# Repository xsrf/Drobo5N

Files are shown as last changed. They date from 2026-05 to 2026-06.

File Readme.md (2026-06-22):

# Drobo 5N Reverse-Engineering
My Drobo 5N (Unit 1) died on me in May 2026. Here are some random notes and resources I gathered, trying to find out what happened.
It looks like one of the three 2 channel SATA Controllers died (more on that later).
I also bought another Drobo 5N (Unit 2) from eBay, to check some of my assumptions.

My assumption was later confirmed. One SATA controller had a bad 1V voltage rail due to a burnt out transistor. Simply replacing that transistor (Q2) fixed the issue.

## Directory Contents

| Directory | Description |
|---|---|
| [3D](3D/) | OpenSCAD and 3D-print files (PCB carriers to help working on the PCB on the desk) |
| [Disassembly](Disassembly/) | Disassembly instructions including images |
| [Datasheets](Datasheets/) | Component datasheets and reference material |
| [gfx](gfx/) | Images used in this repo (figures and photos) |
| [MSP430](MSP430/) | Tools for MSP430 and flash dumps of both units |
| [Unit1](Unit1/) | Unit 1: crashlogs, bootlogs, traces (PulseView), and USB-DOM files/image |
| [Unit2](Unit2/) | Unit 2: crashlogs, bootlogs, traces (PulseView), USB-DOM files |
| [USB-DOM](USB-DOM/) | Disk-on-module images and vxWorks files |

## Crashlog Recovery

### USB DOM (Disk on Module)
The Drobo 5N comes with a 1GB FAT16 formatted internal USB drive. It uses a module which is connected using a 2mm pitch internal USB connector (like the ones on a regular PC motherboard, but smaller). You can make yourself an adapter with 2mm pitch Header-Pins.

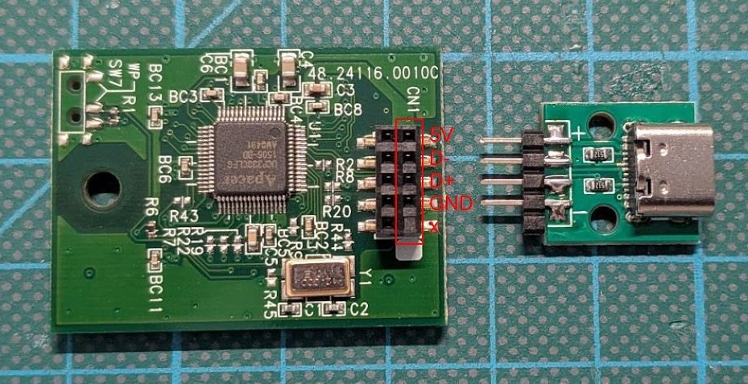
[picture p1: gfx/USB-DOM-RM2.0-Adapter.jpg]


The module holds Crashlogs (basically the whole output of the Drobis internal VxWorks system) which hold valuable information for debugging.

### Crashlogs (Unit 1)
The [crashlogs](Unit1/USB-DOM/UBSW/Crashlogs) I recovered from my unit have a time offset of about ~9h to MESZ. 2026-05-03 03:19 MESZ ~= 2026-05-02 18:19 in log.  
- [crashlog-20260504-1210](Unit1/USB-DOM/UBSW/Crashlogs/crashlog-20260504-1210) shows drobo crashing
- [crashlog-20260504-1211](Unit1/USB-DOM/UBSW/Crashlogs/crashlog-20260504-1211) shows the reason on next bootup: *diskInterfaceInitialise: Adapter 1 Init Failed*

### Timeline (Unit 1)
Together with my local monitoring and my own observations, the crashlogs allow me to reconstruct what happened:
- 2026-05-01 19:34 MESZ Disk 3 dropped out?!?! (Most recent timestamp via UFS Explorer recovery of Disk 3)
- 2026-05-03 03:19 MESZ (+-5min) Drobos httpd went offline (Timestamp via Monitoring)
- 2026-05-04 20:49 MESZ Me noticing Drobo being off with top slot green, 2nd slot red; No sign in Dashboard
- 2026-05-04 20:.. Tried to power off via Switch. Got untill all lights went dark but drive and fan didn't power down even after ~15 minutes; Removed Power-Plug
- 2026-05-04 20:.. Plugged back in, booted, all lights yellow, after few min top red, rest off; Dashboard sees Drobo and says no drives; Drives did not spin up!
- Powered on again without drives then inserted one totally different drive - did not spin up!

## Other components

### Battery
The Battery is a 3.6V 2150mAh Li-Ion 18650 (Panasonic CGR 18650 CH). Model "Bumblebee b".
I measured:
- 4.12V between Red and Black under slight load (Multimeter Low-Z)
- 10k between Green and Black
Looks perfectly fine

### Power-Switch
| Wire | Function |
| --- | --- |
| Blue | Switched to white -> pulls up MSP430 P1.1 |
| White | 3V supply; LED anode |
| Red | LED kathode -> pulled down by MSP430 P4.6 via Q87 |

### Power-Switch LED
During debugging I've observed many flashing patterns
| Signal | Meaning |
| --- | --- |
| on continously | System on; normal operation |
| off continously | System off/stand-by |
| 3x 790ms, 4x 160ms, repeating | Performing Shutdown |
| on 256ms, off 256ms, repeating | System on; PMU (v78) in failsafe mode! |
| extremely faint short flash every ~500ms | PMU (v78) reset-loop |
| one 330ms flash (and short fan twitch) | PMU (v78) enters Failsafe Stand-By after power connect / reset |
| one 300ms, 3x 80ms, 3x 160ms, 3x 80ms, 2x 160ms (and short fan spinup) | PMU (v7a) enters regular Stand-By after power connect / reset |

### PMU - MSP430F2252
The PMU (Power Management Unit) of the Drobo is a MSP430F2252. It's responsible for handling the Power-Switch, Power-Switch LED, Power-On/Stand-By behaviour and brings up additional power-rails for the SoC, other controllers and Fan.

When the PMU is held in reset, the FAN and Power Switch LED are turned on!

#### J11 - MSP430F2252 programming header

J11 (not populated 0.1" header) exposes the programming / debugging pins of the MSP430.

| Pin | Function |
| --- | --- |
| 1 | 3V (marked) |
| 2 | TEST |
| 3 | RST |
| 4 | GND |

Jumper J13 must be removed in order to debug/reset/flash the MSP during operation.
While flashing, FAN might tun on.
Didn't try supplying 3V through J11.

#### Flash/Memory Layout
| Range | Name | Info |
| --- | --- | --- |
| 0x0C00 - 0x0FFF | Boot | 1kb; Identical on Unit1/Unit2; probably stock TI |
| 0x1000 - 0x10FF | Info | 256b; INFOD to INFOA |
| 0xC000 - 0xFFFF | Main/Code | 16kb |

Remove J13 to read/write to MSP430 while drobo is powered (plugged in is enough).

#### Info Segments
| Range | Name | Info |
| --- | --- | --- |
| 0x1000 - 0x103F | Info D | PMU version; static values; programmed with PMU update |
| 0x1040 - 0x107F | Info C | PMU runtime information; updated on every reset and power-up |
| 0x1080 - 0x10BF | Info B | static informatiion?! |
| 0x10C0 - 0x10FF | Info A | FF + Chip calibration values at end; write protected |

Only Info D is written when a PMU update is performed by the VxWorks system. 

#### Info C
0x105B (unit8) (probably 0x105A uint16) looks like it contains a counter that increments with every boot-up of the system

0x1065 (unit8) (probably 0x1064 uint16) contains a counter that's incremented whenever the PMU starts

#### UART to SoC
The PMU has a 38400 baud UART connection to the main SoC via Pins UCA0RXD/UCA0TXD. It communicates via 0x00 terminated ASCII strings.
Communication can be observed in [powerup_01_safemode_pmu_update.sr](Unit1/Trial-20260621-01/powerup_01_safemode_pmu_update.sr).
Whenever the PMU parses a command from the SoC, the power switch LED goes off (which is to fast to notice in real life).

### PMU Failure Modes

#### Cleared INFO Segments
https://www.youtube.com/live/jLmZw1f3uVw?t=13111

#### Power Switch LED blinking rapidly and extremely faint (look closely in dark!) after plugging in
Probably caused by PMU constantly resetting and initial High-Z output of the PMU turns on the LED for just a few ms.
Probably due to corrupt INFO segment in flash.
https://www.youtube.com/live/jLmZw1f3uVw?t=10425

#### Power Switch LED constantly blinking fast (~500ms 50% duty cicle) after plugging-in
FAN pulsing with LED. No reaction to power switch.
Probably caused by corrupt INFO segment. PMU probably boot-looping.

#### Power Switch LED constantly blinking fast (~500ms 50% duty cicle) after power on
PMU in FailSafe mode; FAN at full speed

### Serial

#### J3 (2.54 Header, populated, Linux)
- 1: 3V3 (marked)
- 2: RX (send to drobo)
- 3: TX @ 3V3 (drobo sends to you)
- 4: GND

#### J2 (2.54 Header, unpopulated, VxWorks)
- 1: 3V3 (marked)
- 2: RX (send to drobo)
- 3: TX @ 3V3 (drobo sends to you)
- 4: GND

## Backplane - I2C IO Expanders (TCA9555)

### U13 - LEDs (Addr: 0x20)
- A0: GND
- A1: GND
- A2: GND
- P00: SLOT3_greenLed
- P01: SLOT3_redLed
- P02: SLOT2_greenLed
- P03: SLOT2_redLed
- P04: SLOT1_greenLed
- P05: SLOT1_redLed
- P06: SLOT0_greenLed
- P07: SLOT0_redLed
- P10: SLOT4_greenLed
- P11: SLOT4_redLed
- P12: TP22
- P13: TP21
- P14: TP20
- P15: TP19
- P16: TP18
- P17: TP17

### U15 - Disks (Addr: 0x23)
- A0: Vcc
- A1: Vcc
- A2: GND
- P00: SLOT3_diskPower
- P01: SLOT2_diskPower
- P02: SLOT1_diskPower
- P03: SLOT0_diskPower
- P04: SLOT4_diskPower
- P05: TP26
- P06: TP27
- P07: TP28
- P10: SLOT3_diskPresence
- P11: SLOT2_diskPresence
- P12: SLOT1_diskPresence
- P13: SLOT0_diskPresence
- P14: SLOT4_diskPresence
- P15: TP2x
- P16: TP2x
- P17: TP2x

### Disk sensing
Pin 6 of the SATA Connector (GND) is connected through 5K (R1/2/7/8/20) to an input on U15 Port 1.
The Input is pulled-down to GND via 100K.

> [!WARNING]  
> No clue how this should work. The input would always be pulled down?! However, I2C later reads all HIGH when no disk is connected

### I2C

GPIO Extenders U13 and U15 are controlled via I2C commands:

#### Drobo PowerOff
Measured on faulty Unit 1:
```
W 23 02 00 -> Output Port 0 (P00-P07) ALL OFF
```
#### Drobo PowerUp
Measured on faulty Unit 1 with no disk in place:
```
W 23 07 FF      P1 CNF ALL IN
R 23 01 :: FF   P1 GET ALL HIGH (diskPresence -> no disk present)

W 23 02 00      P0 SET ALL LOW
W 23 06 00      P0 CNF ALL OUT
W 23 03 00      P1 SET ALL LOW
W 23 07 1F      P1 CNF 0001 1111 (diskPresence IN)
```

Mesured on working Unit 1 with disk in slot 0:
```
W 23 07 FF      P1 CNF ALL IN
R 23 01 :: F7   P1 GET 11110111 (diskPresence -> Disk in Slot 0)

W 23 06 00      P0 CNF ALL OUT
W 23 02 00      P0 SET ALL LOW
W 23 07 1F      P1 CNF 0001 1111 (diskPresence IN)
W 23 03 00      P1 SET ALL LOW

R 23 01 :: 17   P1 GET 0001 0111 (diskPresence -> Disk in Slot 0)
R 23 01 :: 17   P1 GET 0001 0111 (diskPresence -> Disk in Slot 0)
R 23 01 :: 17   P1 GET 0001 0111 (diskPresence -> Disk in Slot 0)
R 23 01 :: 17   P1 GET 0001 0111 (diskPresence -> Disk in Slot 0)
R 23 01 :: 17   P1 GET 0001 0111 (diskPresence -> Disk in Slot 0)
R 23 00 :: 00   P0 GET 0000 0000 (Disk power is all off)
R 23 00 :: 00   P0 GET 0000 0000 (Disk power is all off)
R 23 00 :: 00   P0 GET 0000 0000 (Disk power is all off)
R 23 00 :: 00   P0 GET 0000 0000 (Disk power is all off)
R 23 00 :: 00   P0 GET 0000 0000 (Disk power is all off)
R 23 00 :: 00   P0 GET 0000 0000 (Disk power is all off)
W 23 02 08      P0 SET 0000 1000 (Power Slot 0)
R 23 00 :: 08   P0 GET 0000 1000 (Power is on for Slot 0)
W 23 02 08      P0 SET 0000 1000 (Power Slot 0)
R 23 00 :: 08   P0 GET 0000 1000 (Power is on for Slot 0)
W 23 02 08      P0 SET 0000 1000 (Power Slot 0)
R 23 00 :: 08   P0 GET 0000 1000 (Power is on for Slot 0)
W 23 02 08      P0 SET 0000 1000 (Power Slot 0)
R 23 00 :: 08   P0 GET 0000 1000 (Power is on for Slot 0)
W 23 02 08      P0 SET 0000 1000 (Power Slot 0)
R 23 01 :: 17   P1 GET 0001 0111 (diskPresence -> Disk in Slot 0)
R 23 01 :: 17   P1 GET 0001 0111 (diskPresence -> Disk in Slot 0)
R 23 01 :: 17
R 23 01 :: 17
R 23 01 :: 17
R 23 01 :: 17
...
```

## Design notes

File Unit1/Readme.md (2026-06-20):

# Drobo 5N (Unit 1)
My own unit. One broken SATA Controller. Will power up and show on the network, but won't spin up any drives.

Software-Version: 4.2.1

## Troubleshooting

Suring boot, the VxWorks software shows:
```
  Dumping Disk Adapter Table
    Adapter Instance   Adapter Address   Adapter Data Address
           0            0x014B4298            0x04339C70
           1            0x014B4298            0x00000000
           2            0x014B42A8            0x0431B5D0

   Dumping Disk Slot Config Table:
    Adapter Instance   Connection    Physical Slot   Adapter Channel    Initialised    Device Pointer
        2                DRIVE             0              0                Yes           0x04304218
        1                DRIVE             1              0                 No           0x04304ABC
        1                DRIVE             2              1                 No           0x04305B70
        0                DRIVE             3              0                 No           0x04306414
        0                DRIVE             4              1                 No           0x04306CB8
        2                DRIVE             5              1                 No           0x0430755C
diskInterfaceInitialise: Adapter 1 Init Failed.
showDiskTbs: Dumping Disk Driver Config Tables:

  Dumping Disk Adapter Table
    Adapter Instance   Adapter Address   Adapter Data Address
           0            0x014B4298            0x04339C70
           1            0x014B4298            0x00000000
           2            0x014B42A8            0x0431B5D0

   Dumping Disk Slot Config Table:
    Adapter Instance   Connection    Physical Slot   Adapter Channel    Initialised    Device Pointer
        2                DRIVE             0              0                Yes           0x04304218
        1                DRIVE             1              0                 No           0x04304ABC
        1                DRIVE             2              1                 No           0x04305B70
        0                DRIVE             3              0                 No           0x04306414
        0                DRIVE             4              1                 No           0x04306CB8
        2                DRIVE             5              1                 No           0x0430755C
diskInterfaceInitialise: Completed Disk Driver Initialisation: FAILED
diskInterfacePostInit: Disk Controller Failed to initialise: Forcing system shutdown...
```

This indicates that something is wrong with SATA Adapter 1, which handles Slots 1 and 2. This matches the crashlog, which showed that my Drive in Slot 2 suddenly disappieared.

I've traced the SATA traces from the slots 2 and 3 to U21, Marvel 88SE9120 (with 4M Flash U22).

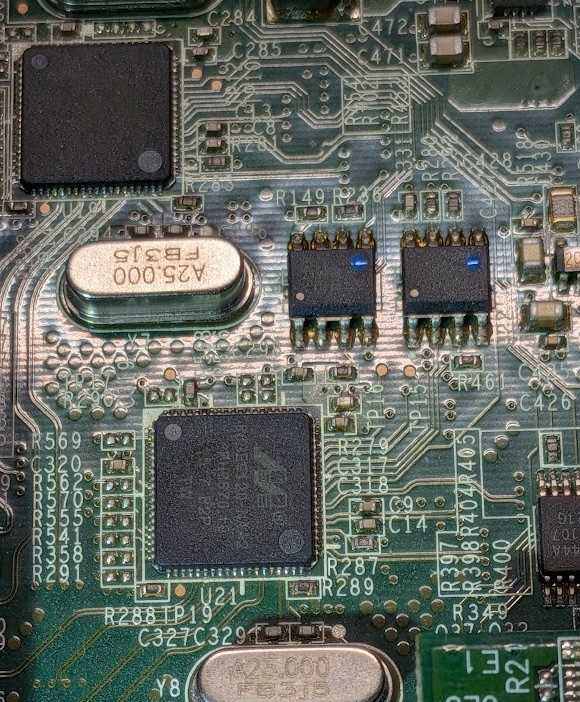
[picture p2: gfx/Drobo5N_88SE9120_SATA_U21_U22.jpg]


A thermal image shows that U21 is ~10°C colder than the working SATA controller U19.

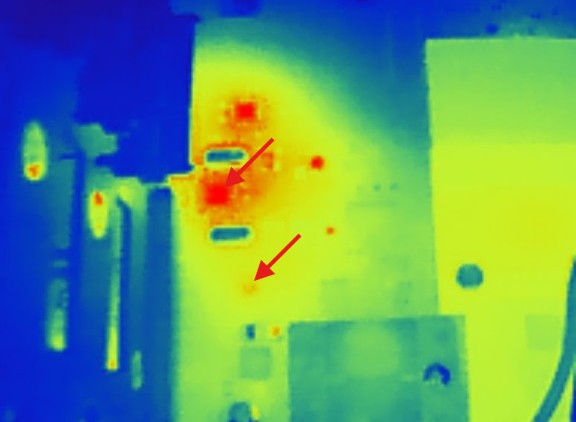
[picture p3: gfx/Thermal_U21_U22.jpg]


Comparing signals on the Flash of the working and dead 88SE9120, shows that U21 is not talking to U22, while U19 indeed talks to U20.

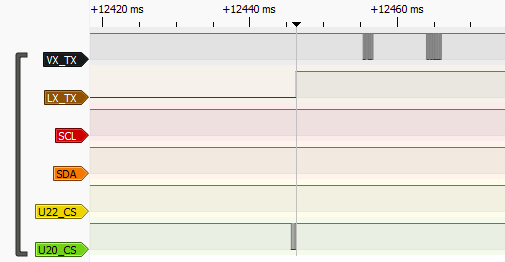
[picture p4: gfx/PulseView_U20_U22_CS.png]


I cannot find a full Datasheet of the 88SE9120, but I found this pinout:

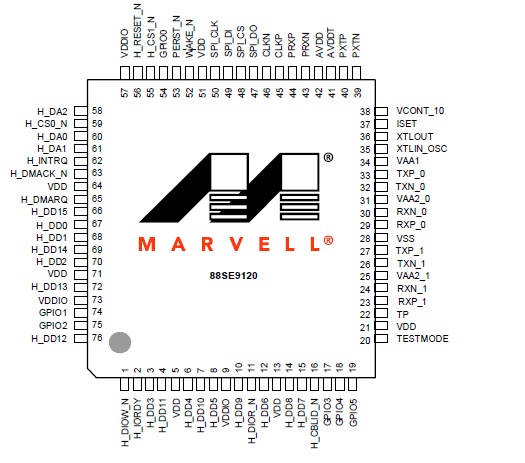
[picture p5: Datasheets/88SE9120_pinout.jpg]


As well as a short [datasheet for the 88SE9125](../Datasheets/88se9125-datasheet-668097cf16614605971775.pdf) which has the same PIN layout.

Both crystals are oscillating.

All Capacitors surrounding U21 on the top measure identical voltages to those around U19, so I guess these voltage rails are fine. The datasheet however mentions VCONT_10 (1.0V) which I cannot find.

Found VCONT_10 and its PNPs on the bottom side of the PCB. VCONT_10 of U21/Q2 is only 0.5V!

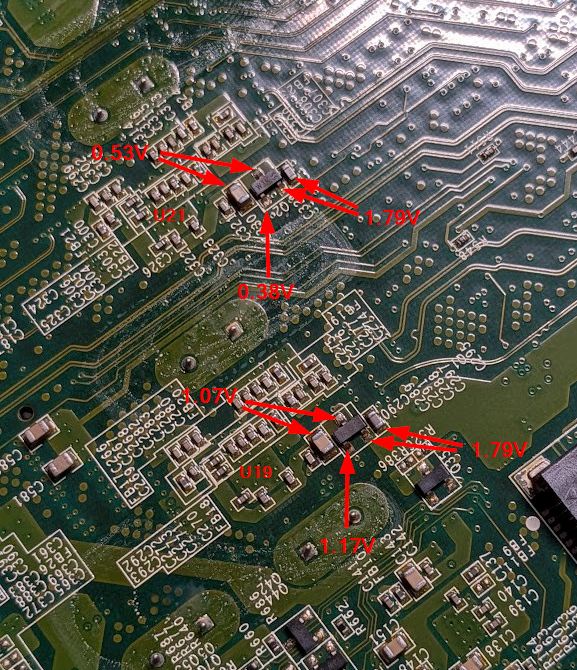
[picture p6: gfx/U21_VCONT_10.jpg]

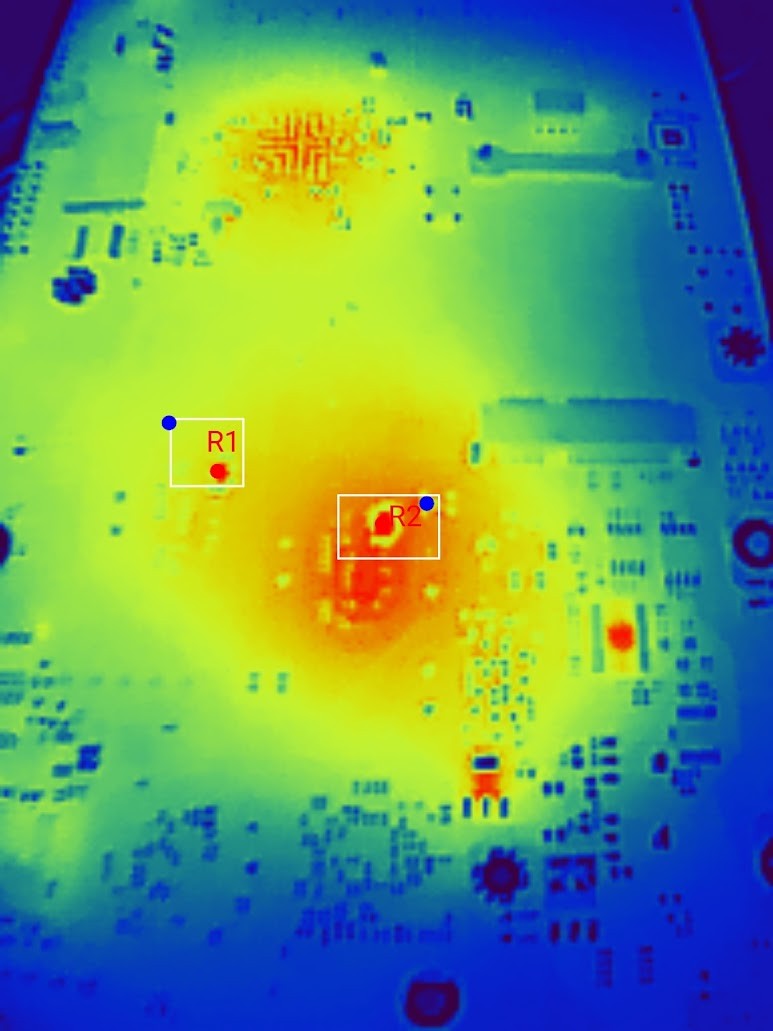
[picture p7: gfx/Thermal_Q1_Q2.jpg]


Q1 for VCONT_10 for U19 (1.0V):  
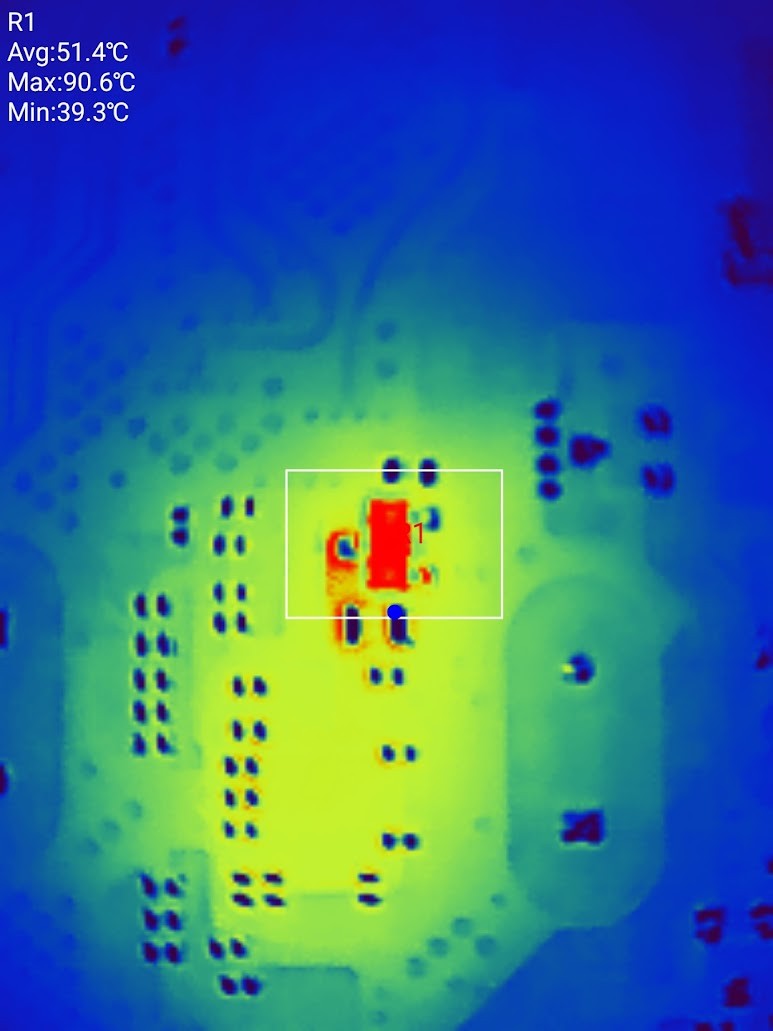
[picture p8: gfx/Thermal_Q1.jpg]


Q2 for VCONT_10 for U21 (0.5V):  
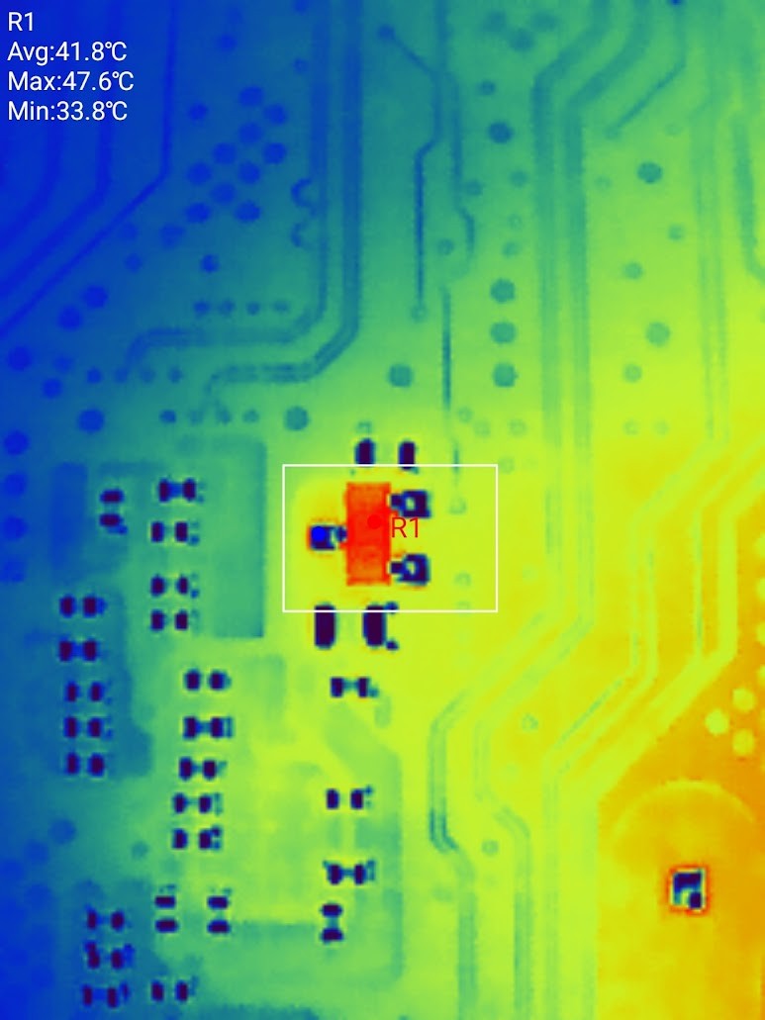
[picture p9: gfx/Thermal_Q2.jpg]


### 2026-06-19

Replacement Q2 arrived. After replacing, the Drobo was completely dead... It was sitting there on my table for 2 weeks and I didn't try it again before soldering. No clue what happened. I then noticed the power switch LED was very faintly blinking (like 10ms on 300ms off). This reminded me of scanlimes issue.

I now dumped the MSP430 flash and found the same issue - the INFO partition was partially overwritten. BSL and MAIN looked fine.

I dumped all partitions from my 2nd unit and the flashed the first half of the working INFO to my Drobo, as this was the corrupt part. Nothing, not even faint blinking anymore. I then flashed the whole INFO partition. But same. I've read the partitions back and noticed the MAIN was all 0xFF?! So I wrote the original back and finally it showed some signs of live!

It powers on, but all bay/front lights stay static and FAN is full power. The Switch LED flashes continuously (~500ms on, 500ms off).
There is no life on the serial ports either. The VxWorks shows a constant HIGH signal, the Linux one stays low.
Pressing the Power-Switch again powers it off.
Q2 generates stable 1V though!!
Same as: https://www.youtube.com/live/jLmZw1f3uVw?t=13111

I then tried to flash INFO and MAIN from the working Unit 2 to my one, and it actually kinda worked!
It powers on and initializes both cores!
The VxWorks reports:

```
82718580-82722723 UART: TX packets: Reading PMU Version...[0D][0A]
82722758-82733343 UART: TX packets: PMU Version: 0.0.0x0000, Failsafe Version 3 (Variant 0x000)[0D][0A]
82733379-82740133 UART: TX packets: Considering an Update to the PMU ... [0D][0A]
82740169-82759459 UART: TX packets: *************************************************************************************************************[0D][0A]
82759494-82778784 UART: TX packets: **** WARNING: PMU is currently running in FAILSAFE mode - limited functionality until it is reprogrammed ****[0D][0A]
82778819-82798109 UART: TX packets: *************************************************************************************************************[0D][0A]
82798144-82798457 UART: TX packets: [0D][0A]
82798492-82810296 UART: TX packets: Unit will be reprogrammed and rebooted due to PMU in Failsafe mode[0D][0A]
82810331-82819872 UART: TX packets: PMU is now in Failsafe Mode...Starting S-Record Dump:[0D][0A]
82819907-82820220 UART: TX packets: [0D][0A]
82820255-83712996 UART: TX packets: [  0]: .[08]PMU read longer than buffer: avail=4, length=2[0D][0A]
83713031-84191766 UART: TX packets: +.[08]+.[08]+.[08]+.[08]+.[08]+.[08]+.[08]+.[08]+.[08]+.[08]+.[08]+.[08]+.[08]+.[08]+.[08]0x40c7bf0 (BusM A): 0x40c7bf0 (BusM A): INFO: usb2Msc - Storage driver got a device attach notification.[0D][0A]
84191801-84203257 UART: TX packets: INFO: usb2Msc - Storage driver got a device attach notification.[0D][0A]
84204701-84404851 UART: TX packets: +.[08]+.[08]+.[08]+.[08]+.[08]+.[08]0x40c7bf0 (BusM A): 0x40c7bf0 (BusM A): INFO: usb2Msc - Mounting device (PDT 0x0 PQ 0x0 RMB 0x0) VID =          : PID = USB DISK MODULE  : REV = PMAP[0D][0A]
84404886-84424176 UART: TX packets: INFO: usb2Msc - Mounting device (PDT 0x0 PQ 0x0 RMB 0x0) VID =          : PID = USB DISK MODULE  : REV = PMAP[0D][0A]
84424211-84446113 UART: TX packets: 0x40c7bf0 (BusM A): 0x40c7bf0 (BusM A): INFO: usb2Msc - Device 0x2 LUN 0 of 1005568 (KB) will be mounted with base name /bd0[0D][0A]
84446148-84461086 UART: TX packets: INFO: usb2Msc - Device 0x2 LUN 0 of 1005568 (KB) will be mounted with base name /bd0[0D][0A]
84461121-84829383 UART: TX packets: +.[08]+.[08]+.[08]+.[08]+.[08]+.[08]+.[08]+.[08]+.[08]+.[08]+.[08]+.[08]+.[08][0D]/bd0/  - disk check in progress ...[0D][0A]
84829418-85056114 UART: TX packets: [0D]/bd0/vxWorks[0D]/bd0/LxImage +.[08][0D]/bd0/bootCount[0D]/bd0/Crashlogs [0D]/bd0/Crashlogs/crashlog-20260216-2342[0D]/bd0/Crashlogs/crashlog-20260224-0358 [0D]/bd0/Crashlogs/crashlog-20260330-1347 [0D]/bd0/Crashlogs/crashlog-20260504-1210 +.[08][0D]/bd0/Crashlogs/crashlog-20260504-1211 [0D]/bd0/Crashlogs/crashlog-20260504-1230 [0D]/bd0/Crashlogs/crashlog-20250728-0308 [0D]/bd0/Crashlogs/crashlog-20250821-1509 [0D]/bd0/Crashlogs/crashlog-20250824-2106 [0D]/bd0/Crashlogs/crashlog-20260504-1241 [0D]/bd0/Crashlogs/crashlog-20260509-0214 [0D]/bd0/Crashlogs/crashlog-20020418-2137 +.[08][0D]/bd0/Crashlogs/crashlog-20020418-2139 [0D]/bd0/Crashlogs/crashlog-20020418-2232 [0D]/bd0/Crashlogs/crashlog-20020418-2242 [0D]/bd0/Crashlogs/crashlog-20020418-2301 [0D]/bd0/Crashlogs/crashlog-20020418-2309 [0D]/bd0/Crashlogs/crashlog-20020418-2321 [0D]/bd0/Crashlogs/crashlog-20020418-2327 [0D]/bd0/Crashlogs/crashlog-20000322-0301 [0D]/bd0/Crashlogs/crashlog-20000322-0315 +.[08][0D]/bd0/Crashlogs/crashlog-20000302-1302 [0D]/bd0/Crashlogs/crashlog-20040602-2355 [0D]/bd0/Crashlogs/crashlog-20800402-0204 [0D]/bd0/Crashlogs/crashlog-20000302-0400 [0D]/bd0/Crashlogs/crashlog-20000302-0417 [0D]/bd0/NoCrashMsg                       [0D]/bd0/hibLog     [0D]/bd0/hibHdr [0D]/bd0/amitLog[0D]/bd0/vxWorks_prev+.[08][0D]/bd0/FlashConfigData[0D]/bd0/J2              [0D]/bd0/J1 +[0D][0A]
85056149-85566885 UART: TX packets: [ 40]: .[08]+.[08]+.[08][0D]/bd0/hdr[0D]/bd0/UBSW.bin+.[08][0D]/bd0/UBSW.hdr [0D]/bd0/LxHdr    [0D]/bd0/runesa.vxe[0D]/bd0/eventLog   [0D]/bd0/hdr_prev [0D]/bd0/LxImage_prev+.[08][0D]/bd0/LxHdr_prev   [0D]/bd0/runesa_prev.vxe[0D]/bd0/rtphdr_prev     [0D]/bd0/userEventLog[0D]/bd0/rtphdr       [0D]/bd0/J1TAGS [0D]/bd0/AMIT   +.[08][0D]/bd0/RebootReason[0D]/bd0/System Volume Information[0D]/bd0/System Volume Information/WPSettings.dat[0D]/bd0/System Volume Information/IndexerVolumeGuid[0D]/bd0/$RECYCLE.BIN                                [0D]/bd0/$RECYCLE.BIN/desktop.ini                    +.[08][0D]                                                                                                                    [0D]+.[08]+.[08]+.[08]+.[08]+.[08]+.[08]+.[08]+.[08]+.[08]+.[08][0D]/bd0/  - Volume is OK [0D][0A]
85566920-85567233 UART: TX packets: [0D][0A]
85567268-85574197 UART: TX packets:           total # of clusters:  62,580[0D][0A]
85574232-85580813 UART: TX packets:          # of free clusters:  44,635[0D][0A]
85580848-85586558 UART: TX packets:           # of bad clusters:  0[0D][0A]
85586593-85593870 UART: TX packets:            total free space:  714,160 Kb[0D][0A]
85593905-86007156 UART: TX packets: +.[08]+.[08]+.[08]+.[08]+.[08]+.[08]+.[08]+.[08]+.[08]+.[08]+.[08]+.[08]+.[08]    max contiguous free space:  731,136,000 bytes[0D][0A]
86007191-86013076 UART: TX packets:                  # of files:  56[0D][0A]
86013111-86018821 UART: TX packets:                # of folders:  3[0D][0A]
86018856-86026133 UART: TX packets:        total bytes in files:  286,602 Kb[0D][0A]
86026168-86031879 UART: TX packets:            # of lost chains:  0[0D][0A]
86031914-86037972 UART: TX packets:    total bytes in lost chains:  0[0D][0A]
86038007-86338819 UART: TX packets: +.[08]+.[08]+.[08]+.[08]+.[08]+.[08]+.[08]+.[08]+.[08]+.[08]+[0D][0A]
86338854-87672320 UART: TX packets: [ 80]: .[08]+.[08]+.[08]+.[08]+.[08]+.[08]+.[08]+.[08]+.[08]+.[08]+.[08]+.[08]+.[08]+.[08]+.[08]+.[08]+.[08]+.[08]+.[08]+.[08]+.[08]+.[08]+.[08]+.[08]+.[08]+.[08]+.[08]+.[08]+.[08]+.[08]+.[08]+.[08]+.[08]+.[08]+.[08]+.[08]+.[08]+.[08]+.[08]+.[08]+[0D][0A]
87672355-88130586 UART: TX packets: [120]: .[08]+.[08]+.[08]+.[08]+.[08]+.[08]+.[08]+.[08]+.[08]+.[08]+.[08]+.[08]+.[08]+.[08]0x37078e0 (tErfTask): 0x37078e0 (tErfTask): INFO: usb2Msc - Device /bd0 has been claimed by filesystem[0D][0A]
88130621-88141032 UART: TX packets: INFO: usb2Msc - Device /bd0 has been claimed by filesystem[0D][0A]
88141067-88151652 UART: TX packets: NOTIFY: hDevice 0x2 lun 0 medium changed (mediumInsert = 1)[0D][0A]
88151687-89005776 UART: TX packets: +.[08]+.[08]+.[08]+.[08]+.[08]+.[08]+.[08]+.[08]+.[08]+.[08]+.[08]+.[08]+.[08]+.[08]+.[08]+.[08]+.[08]+.[08]+.[08]+.[08]+.[08]+.[08]+.[08]+.[08]+.[08]+.[08]+[0D][0A]
89005811-90339273 UART: TX packets: [160]: .[08]+.[08]+.[08]+.[08]+.[08]+.[08]+.[08]+.[08]+.[08]+.[08]+.[08]+.[08]+.[08]+.[08]+.[08]+.[08]+.[08]+.[08]+.[08]+.[08]+.[08]+.[08]+.[08]+.[08]+.[08]+.[08]+.[08]+.[08]+.[08]+.[08]+.[08]+.[08]+.[08]+.[08]+.[08]+.[08]+.[08]+.[08]+.[08]+.[08]+[0D][0A]
90339308-91672771 UART: TX packets: [200]: .[08]+.[08]+.[08]+.[08]+.[08]+.[08]+.[08]+.[08]+.[08]+.[08]+.[08]+.[08]+.[08]+.[08]+.[08]+.[08]+.[08]+.[08]+.[08]+.[08]+.[08]+.[08]+.[08]+.[08]+.[08]+.[08]+.[08]+.[08]+.[08]+.[08]+.[08]+.[08]+.[08]+.[08]+.[08]+.[08]+.[08]+.[08]+.[08]+.[08]+[0D][0A]
91672806-93006270 UART: TX packets: [240]: .[08]+.[08]+.[08]+.[08]+.[08]+.[08]+.[08]+.[08]+.[08]+.[08]+.[08]+.[08]+.[08]+.[08]+.[08]+.[08]+.[08]+.[08]+.[08]+.[08]+.[08]+.[08]+.[08]+.[08]+.[08]+.[08]+.[08]+.[08]+.[08]+.[08]+.[08]+.[08]+.[08]+.[08]+.[08]+.[08]+.[08]+.[08]+.[08]+.[08]+[0D][0A]
93006305-94339764 UART: TX packets: [280]: .[08]+.[08]+.[08]+.[08]+.[08]+.[08]+.[08]+.[08]+.[08]+.[08]+.[08]+.[08]+.[08]+.[08]+.[08]+.[08]+.[08]+.[08]+.[08]+.[08]+.[08]+.[08]+.[08]+.[08]+.[08]+.[08]+.[08]+.[08]+.[08]+.[08]+.[08]+.[08]+.[08]+.[08]+.[08]+.[08]+.[08]+.[08]+.[08]+.[08]+[0D][0A]
94339800-95673304 UART: TX packets: [320]: .[08]+.[08]+.[08]+.[08]+.[08]+.[08]+.[08]+.[08]+.[08]+.[08]+.[08]+.[08]+.[08]+.[08]+.[08]+.[08]+.[08]+.[08]+.[08]+.[08]+.[08]+.[08]+.[08]+.[08]+.[08]+.[08]+.[08]+.[08]+.[08]+.[08]+.[08]+.[08]+.[08]+.[08]+.[08]+.[08]+.[08]+.[08]+.[08]+.[08]+[0D][0A]
95673339-97006801 UART: TX packets: [360]: .[08]+.[08]+.[08]+.[08]+.[08]+.[08]+.[08]+.[08]+.[08]+.[08]+.[08]+.[08]+.[08]+.[08]+.[08]+.[08]+.[08]+.[08]+.[08]+.[08]+.[08]+.[08]+.[08]+.[08]+.[08]+.[08]+.[08]+.[08]+.[08]+.[08]+.[08]+.[08]+.[08]+.[08]+.[08]+.[08]+.[08]+.[08]+.[08]+.[08]+[0D][0A]
97006836-98340261 UART: TX packets: [400]: .[08]+.[08]+.[08]+.[08]+.[08]+.[08]+.[08]+.[08]+.[08]+.[08]+.[08]+.[08]+.[08]+.[08]+.[08]+.[08]+.[08]+.[08]+.[08]+.[08]+.[08]+.[08]+.[08]+.[08]+.[08]+.[08]+.[08]+.[08]+.[08]+.[08]+.[08]+.[08]+.[08]+.[08]+.[08]+.[08]+.[08]+.[08]+.[08]+.[08]+[0D][0A]
98340296-99673754 UART: TX packets: [440]: .[08]+.[08]+.[08]+.[08]+.[08]+.[08]+.[08]+.[08]+.[08]+.[08]+.[08]+.[08]+.[08]+.[08]+.[08]+.[08]+.[08]+.[08]+.[08]+.[08]+.[08]+.[08]+.[08]+.[08]+.[08]+.[08]+.[08]+.[08]+.[08]+.[08]+.[08]+.[08]+.[08]+.[08]+.[08]+.[08]+.[08]+.[08]+.[08]+.[08]+[0D][0A]
99673789-101007251 UART: TX packets: [480]: .[08]+.[08]+.[08]+.[08]+.[08]+.[08]+.[08]+.[08]+.[08]+.[08]+.[08]+.[08]+.[08]+.[08]+.[08]+.[08]+.[08]+.[08]+.[08]+.[08]+.[08]+.[08]+.[08]+.[08]+.[08]+.[08]+.[08]+.[08]+.[08]+.[08]+.[08]+.[08]+.[08]+.[08]+.[08]+.[08]+.[08]+.[08]+.[08]+.[08]+[0D][0A]
101007286-102340754 UART: TX packets: [520]: .[08]+.[08]+.[08]+.[08]+.[08]+.[08]+.[08]+.[08]+.[08]+.[08]+.[08]+.[08]+.[08]+.[08]+.[08]+.[08]+.[08]+.[08]+.[08]+.[08]+.[08]+.[08]+.[08]+.[08]+.[08]+.[08]+.[08]+.[08]+.[08]+.[08]+.[08]+.[08]+.[08]+.[08]+.[08]+.[08]+.[08]+.[08]+.[08]+.[08]+[0D][0A]
102340789-103674249 UART: TX packets: [560]: .[08]+.[08]+.[08]+.[08]+.[08]+.[08]+.[08]+.[08]+.[08]+.[08]+.[08]+.[08]+.[08]+.[08]+.[08]+.[08]+.[08]+.[08]+.[08]+.[08]+.[08]+.[08]+.[08]+.[08]+.[08]+.[08]+.[08]+.[08]+.[08]+.[08]+.[08]+.[08]+.[08]+.[08]+.[08]+.[08]+.[08]+.[08]+.[08]+.[08]+[0D][0A]
103674284-104841325 UART: TX packets: [600]: .[08]+.[08]+.[08]+.[08]+.[08]+.[08]+.[08]+.[08]+.[08]+.[08]+.[08]+.[08]+.[08]+.[08]+.[08]+.[08]+.[08]+.[08]+.[08]+.[08]+.[08]+.[08]+.[08]+.[08]+.[08]+.[08]+.[08]+.[08]+.[08]+.[08]+.[08]+.[08]+.[08]+.[08]+.[08]+.[08]![0D][0A]
104841360-104852119 UART: TX packets: ...Sending Final (S9) Record ... PMU-reboot should follow...[0D][0A]

```

Then it reboots and the Power Switch LED and Fan (!) blinks on/off every 500ms. It won't respond to the power switch. Unpluging and repluging immediately causes this blinking.

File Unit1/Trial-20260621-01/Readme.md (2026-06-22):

# Trial 2026-06-21 - 01: PMU Update

I've had the PMU starting in failsafe mode many times after flashing MAIN and INFO from the working unit to this one.
Every time the System booted, the VxWorks system has senn the PMU in failsafe mode and reflashed the PMU.
When reflash finished, the PMU turned the system off and the continously flashed LED+FAN in ~500ms interval. Pressing the button did nothing.
Removing power and replugging ended up in the same state.

My plan was to record traces of the PMU communication while this happened.

So I hooked up my probes not only to the Linux and VxWorks UART but also to the PMU UART and Power Switch LED.

I then dumped the flash (fw_msp_2026-06-21_19-39-40) of the MSP once again, which leaves the PMU in reset, causing FAN and LED permanently on. To reset the PMU, I ran mspdebug and exited it, which lets the PMU run again.

It did, with a confirming ~200ms Blink of the LED and FAN, as usual.

I then hit record in PulseView (powerup_01) and powered the System on.

As usual, it started in Failsafe and VxWorks flashed the PMU. But to my surprise - after PMU flashing, the LED did a blinky dance and the System powered off completely. To the first time ever it looked like the PMU update worked?!

I dumped the Flash again (fw_msp_2026-06-21_20-01-51) and reset the MSP using mspdebug.

It again did a short funky blinky thing on the Power switch which I didn't capture.

Then I recorded again (powerup_02) in PulseView and immediately saw that the PMU was not in failsafe anymore!

I let it run for a while and then powered off. It looks like it was running just fine.

I dumped the flash once again (fw_msp_2026-06-21_20-33-56)

This time I aso captured the Power Switch LED Blinking after `exit` in `mspdebug`.

I powered up once again and captured it, powered off again.

Then I plugged in the Battery, LAN and a Disk in Slot 0.

Captured and Powered Up!

Interesting fact, the PMU now reports as `PMU Version: 1.0.0x007a, Download Version 122 (Variant 0) [Failsafe Ver 3]`. Before all this, when the PMU was fine and the SATA controller was the issue, it reported as `PMU Version: 1.0.0x0078, Download Version 120 (Variant 0) [Failsafe Ver 3]` and VxWorks was fine. Maybe Firmware 4.2.1 accepts both as valid but shipps with `1.0.0x007a`?

No clue why it now finally fixed itself!

Might be important: During all this the MSP-EXP430G2 debugger was connected and the Jumper J13 was removed.

## Timeline
- fw_msp_2026-06-21_19-39-40
- powerup_01
- fw_msp_2026-06-21_20-01-51
- powerup_02
- fw_msp_2026-06-21_20-33-56
- pws_led_blink_after_mspdebug_exit
- powerup_03
- powerup_04 (with hdd)
- fw_msp_2026-06-21_21-32-37

## File-Hashes
```
fw_msp_2026-06-21_19-39-40_all.hex             f37e4395118e87baa999cb87a1dc1588
fw_msp_2026-06-21_19-39-40_bsl.bin             1597be47dfb3ff5691237c399af98363
fw_msp_2026-06-21_19-39-40_bsl.hex             494ea8995a5e5cf3dc2c4cd97f1b0822
fw_msp_2026-06-21_19-39-40_info.bin            4fadb5c3f8ebcc03420263dad8efb7e6
fw_msp_2026-06-21_19-39-40_info.hex            b03e8c64e0cd2e6b76ec0c4ca9ef0887
fw_msp_2026-06-21_19-39-40_main.bin            891151b5a212570fb0ae076e054da34e
fw_msp_2026-06-21_19-39-40_main.hex            837404044c66fa5d39c0c882d7aaa984
fw_msp_2026-06-21_20-01-51_all.hex             9bca0fa6755b7072e911425d5b85ebdc
fw_msp_2026-06-21_20-01-51_bsl.bin             1597be47dfb3ff5691237c399af98363
fw_msp_2026-06-21_20-01-51_bsl.hex             494ea8995a5e5cf3dc2c4cd97f1b0822
fw_msp_2026-06-21_20-01-51_info.bin            df1396b0ca8081cc6bdab26871d9c7c6
fw_msp_2026-06-21_20-01-51_info.hex            8ee6b8d8bda03b83dbb831cee497a290
fw_msp_2026-06-21_20-01-51_main.bin            9e494d79aed6a20fe877c2cab423a509
fw_msp_2026-06-21_20-01-51_main.hex            4913f3cb7d4d6b50f1903d3595f6d7fa
fw_msp_2026-06-21_20-33-56_all.hex             8821c6a4191679b5179bce775eeacf11
fw_msp_2026-06-21_20-33-56_bsl.bin             1597be47dfb3ff5691237c399af98363
fw_msp_2026-06-21_20-33-56_bsl.hex             494ea8995a5e5cf3dc2c4cd97f1b0822
fw_msp_2026-06-21_20-33-56_info.bin            4eede758837c5fd29221d0531341cc6b
fw_msp_2026-06-21_20-33-56_info.hex            c60e63d910ffd1d15e16e4294490f458
fw_msp_2026-06-21_20-33-56_main.bin            9e494d79aed6a20fe877c2cab423a509
fw_msp_2026-06-21_20-33-56_main.hex            4913f3cb7d4d6b50f1903d3595f6d7fa
fw_msp_2026-06-21_21-32-37_all.hex             373f1b379c50739d7566657384df8c7b
fw_msp_2026-06-21_21-32-37_bsl.bin             1597be47dfb3ff5691237c399af98363
fw_msp_2026-06-21_21-32-37_bsl.hex             494ea8995a5e5cf3dc2c4cd97f1b0822
fw_msp_2026-06-21_21-32-37_info.bin            e8cc2223758b5345f1cc710c277e43e3
fw_msp_2026-06-21_21-32-37_info.hex            1ac2cb4b297a566ff39554628db4be1f
fw_msp_2026-06-21_21-32-37_main.bin            9e494d79aed6a20fe877c2cab423a509
fw_msp_2026-06-21_21-32-37_main.hex            4913f3cb7d4d6b50f1903d3595f6d7fa
```

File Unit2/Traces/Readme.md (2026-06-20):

# Traces

Traces of both UARTs and I2C recorded using PulseView @ 1MHz. Open with [Sigrok PulseView](https://sigrok.org/wiki/PulseView).

| Trace | Description |
|---|---|
| power_on_1 | First power-on after disassembly with one new drive in slot 0 (top); timestamp is wrong as battery was disconnected; Drobo is creating a new DiskPack on this drive |
| power_on_2 | 2nd boot with the previously installed drive still in slot 0. |
| poweroff_fail | after running for longer I powered off, but the disk and Fan stayed on. The disk was doing something when I powered off. It has known bad sectors, maybe internal housekeeping. Not sure if that prevented proper shutdown.

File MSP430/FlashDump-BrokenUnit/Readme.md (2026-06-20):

Created from my Drobo 5N Unit 1 which worked before, then suddenly broke.
The MSP430 instantly boot-loops, causing the power swithc LED to constantly flicker really faintly.
The Drobo Firmware Version was 4.2.1.
The PMU version reported to VxWorks when worked was `PMU Version: 1.0.0x0078, Download Version 120 (Variant 0) [Failsafe Ver 3]`

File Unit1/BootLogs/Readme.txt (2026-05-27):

# BootLogs
Captured using two 3V USB-UART Adapters and 2 instances of HTerm.

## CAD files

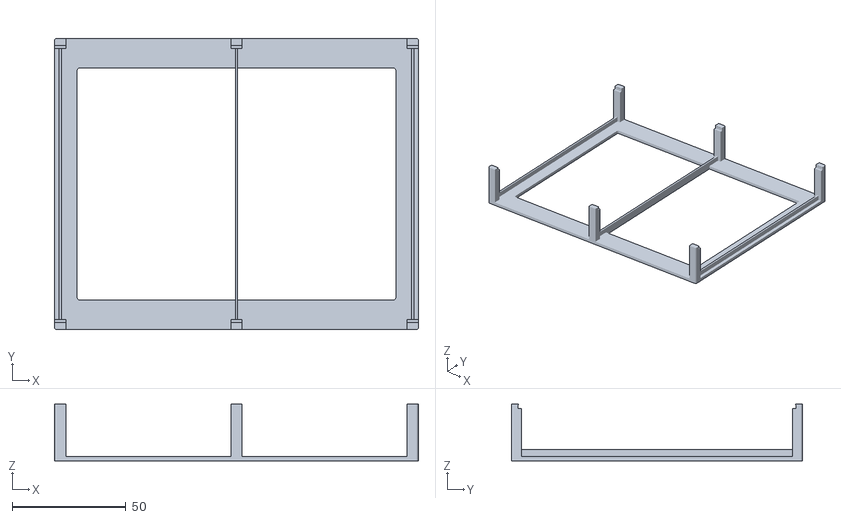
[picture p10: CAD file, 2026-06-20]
3D/Drobo-PCB-Carrier3.stl
160.0 x 128.0 x 25.0

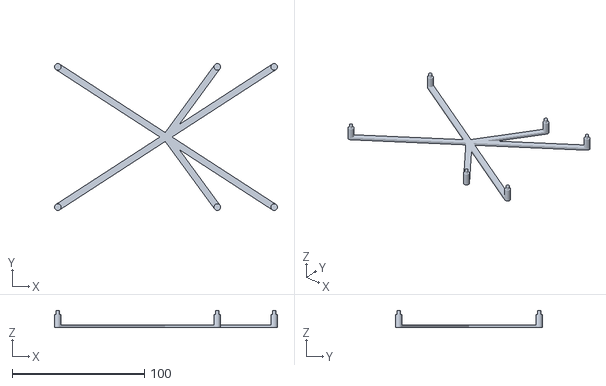
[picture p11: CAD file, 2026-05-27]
3D/Drobo-PCB-Carrier.stl
168.5 x 111.0 x 13.0

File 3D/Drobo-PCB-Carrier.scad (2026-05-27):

$fn = 32;
$pos = [
    [0,0],
    [120.5,0],
    [163.5,0],
    [0,106],
    [120.5,106],
    [163.5,106]
];
$mid = $pos[5]/2;

for($p = $pos) {
    t($p) standoff();
    hull() {
        t($p) cylinder(r=5/2,h=2);
        t($mid) cylinder(r=5/2,h=2);
    }
}




module standoff() {
    cylinder(r=2.8/2,h=13);
    cylinder(r=5/2,h=10);
    
}



module rcube(dim,r=1) {
    linear_extrude(dim[2]) offset(r) square([dim[0]-2*r,dim[1]-2*r],center=true);
}

module rcubeo(dim,r=1) {
    linear_extrude(dim[2]) offset(r) square([dim[0],dim[1]],center=true);
}

module zcube(dim) {
    translate([0,0,dim[2]/2]) cube(dim,center=true);
}

module t(dim) translate(dim) children();

module z(dim) translate([0,0,dim]) children();

module r(dim) rotate(dim) children();

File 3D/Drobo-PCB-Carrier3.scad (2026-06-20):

$dx = 160;
$dy = 122;
$fn = 32;
$h = 25;



difference() {
    rcube([$dx,$dy+6,$h],1);
    rcube([$dx-20,$dy-20,$h+2],1);
    // PCB Dummy:
    z($h-2) hull() {
        zcube([$dx+20,$dy,1.6]);
        zcube([$dx+20,$dy-1,2.5]);
    }
    z(2)zcube([$dx+20,$dy-3,$h-4]);
    t([($dx-15)/4+2.5,0,2])zcube([($dx-15)/2,$dy+10,$h+3]);
    t([($dx-15)/-4-2.5,0,2])zcube([($dx-15)/2,$dy+10,$h+3]);
}

for(i=[-1,0,1]) t([i*($dx/2-2.5),0,0]) zcube([1,$dy,5]);





module rcube(dim,r=1) {
    linear_extrude(dim[2]) offset(r) square([dim[0]-2*r,dim[1]-2*r],center=true);
}

module rcubeo(dim,r=1) {
    linear_extrude(dim[2]) offset(r) square([dim[0],dim[1]],center=true);
}

module zcube(dim) {
    translate([0,0,dim[2]/2]) cube(dim,center=true);
}

module t(dim) translate(dim) children();

module z(dim) translate([0,0,dim]) children();

module r(dim) rotate(dim) children();

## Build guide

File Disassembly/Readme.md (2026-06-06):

# Disassembly
Disassembly instructions for the Drobo 5N

## Prerequisites
- PH1 screwdriver ⊕
- PH2 screwdriver ⊕
- ~3mm flat hat screwdriver ⊖

## Instructions in shot text form
1. Remove magnetic front cover
1. Remove drives
1. Unhook door from bottom opening
1. Unscrew bottom feet (4x PH2)
1. Lift the outer shell slightly at the half with the opening and slide the inner parts out to the back end (pay attention to the plastic catch, it remains part of the housing)
1. The front rubber seal around the drive cage might have got loose now, remove it
1. Unclip the back plastic (2 clips on each side, one on the top)
1. Unclip the front plastic (2 clips on each side, one on the top)
1. Remove the top and bottom screw on each side (4x PH1)
1. Slide the top of the case backwards (against the sides) for ~3-5mm and then turn the case around on its top
1. Try to pry the bottom part of the back (where the connector openings are) backwards. A flat hat screwdriver might help to lever against the chamfered edges
1. Turn it back right way up
1. Slide tha top/back all the way back until the back side is free - then lift it carefully ~10mm. Be aware of the Power switch and Fan cables inside!
1. Carefully unplug the power switch from the right side, then unplug the Fan (can be done from the left side)
1. Remove the top/back
1. optionally: Use a flat hat screw driver or a dull pin to push out the plastic pegs, that hold the Fan, from the back side. Then unclip the Fan cable clips and remove the Fan
1. optionally: Remove the Power switch by pushing it from the back while carefully compressing the flaps on the side with a flat hat screwdriver
1. Unplug the battery
1. Remove the remaining two screws on each side (4x PH1)
1. Carefully lift the backplane assembly up
1. Unscrew the backplane from its frame (8x PH2)
1. Unscrew battery holder from its frame (2x PH2)
1. Unscrew the main PCB and its shield (6x PH1)
1. Carefully lift the PCB shield without bending its fingers on the side
1. Remove the main PCB
1. optionally: Unscrew the USB DOM (Disk on module) and lift it (1x PH1)

## Instructions including images
1. Remove magnetic front cover
1. Remove drives
1. Unhook door from bottom opening
1. Unscrew bottom feet (4x PH2)  
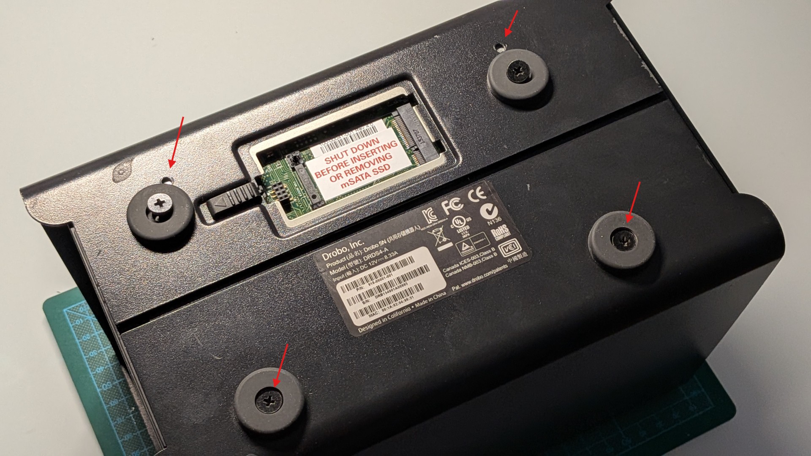
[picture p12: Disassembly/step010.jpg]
   
1. Lift the outer shell slightly at the half with the opening and slide the inner parts out to the back end (pay attention to the plastic catch, it remains part of the housing)  
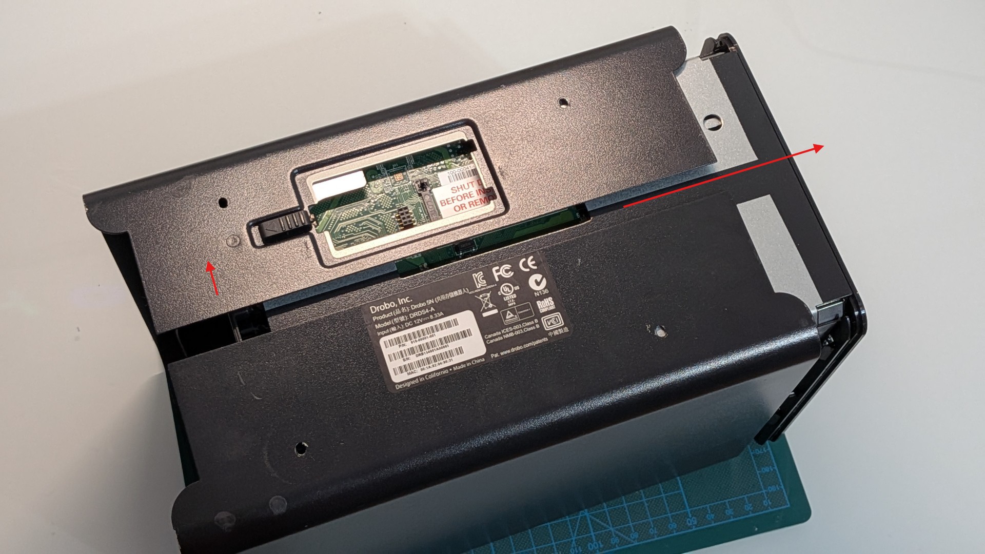
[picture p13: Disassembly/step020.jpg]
   
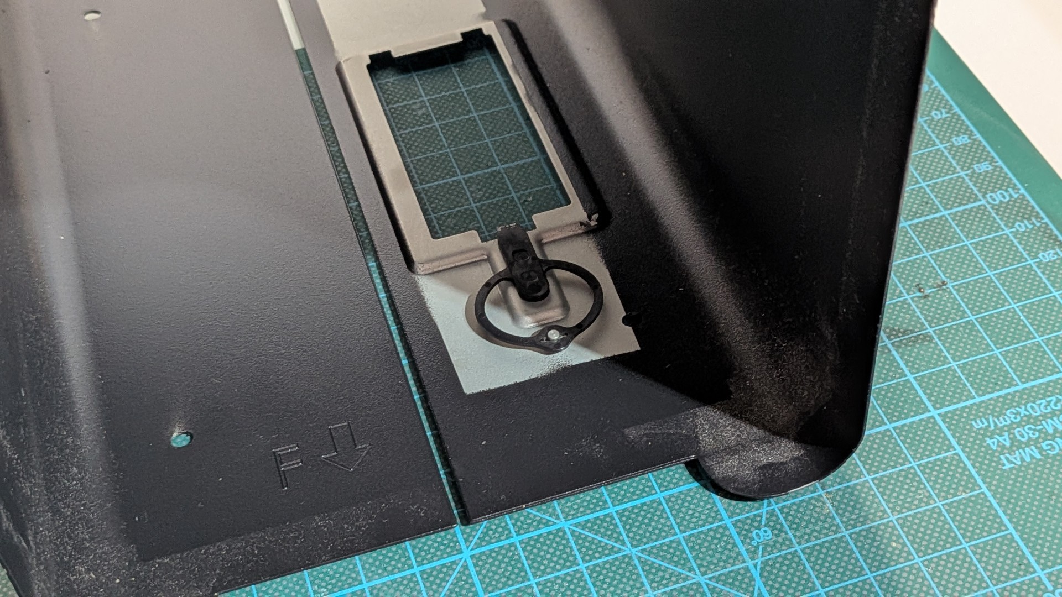
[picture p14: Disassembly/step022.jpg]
   
1. The front rubber seal around the drive cage might have got loose now, remove it  
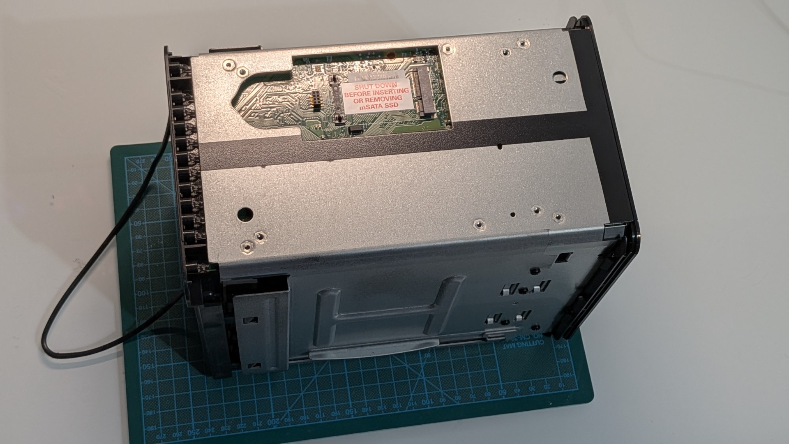
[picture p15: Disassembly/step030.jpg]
   
1. Unclip the back plastic (2 clips on each side, one on the top)  
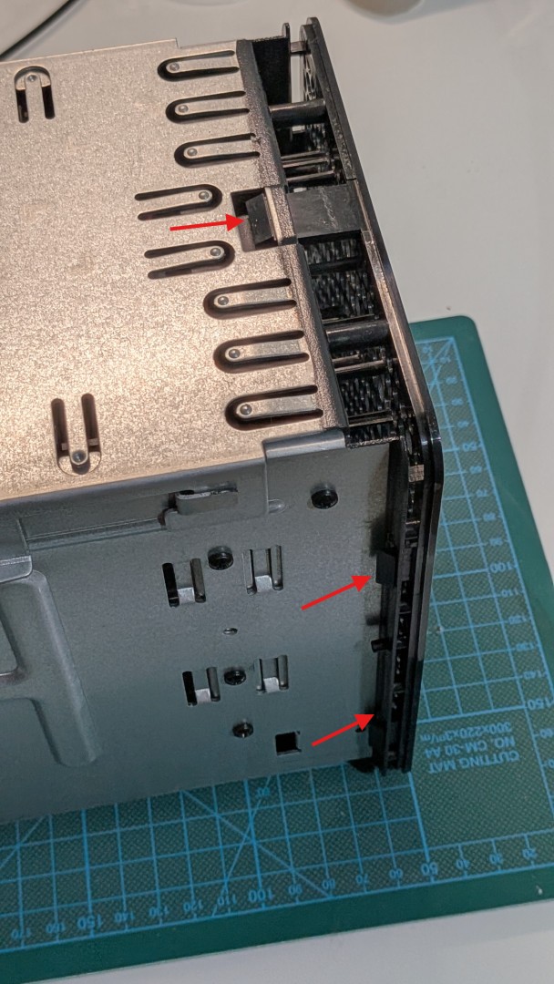
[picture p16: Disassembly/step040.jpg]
   
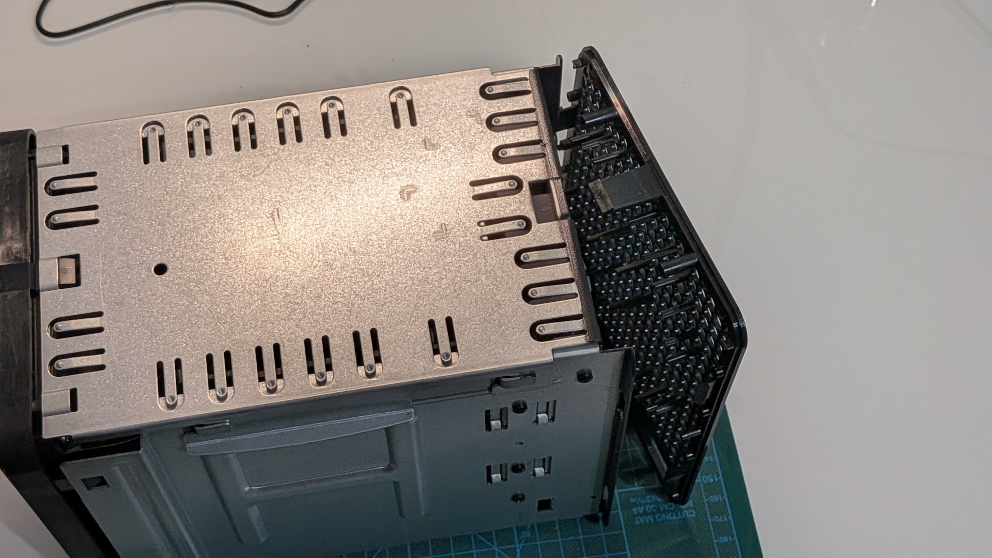
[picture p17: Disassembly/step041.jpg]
   
1. Unclip the front plastic (2 clips on each side, one on the top) and pull the drive cage out  
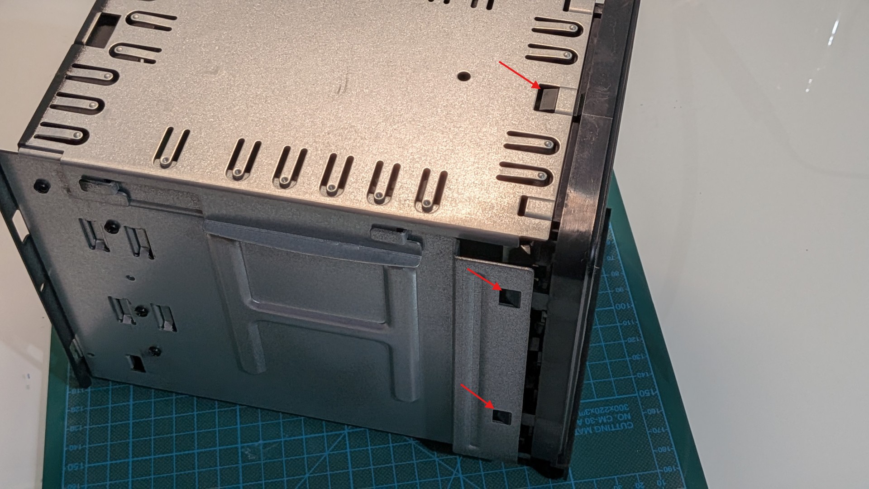
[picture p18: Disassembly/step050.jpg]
   
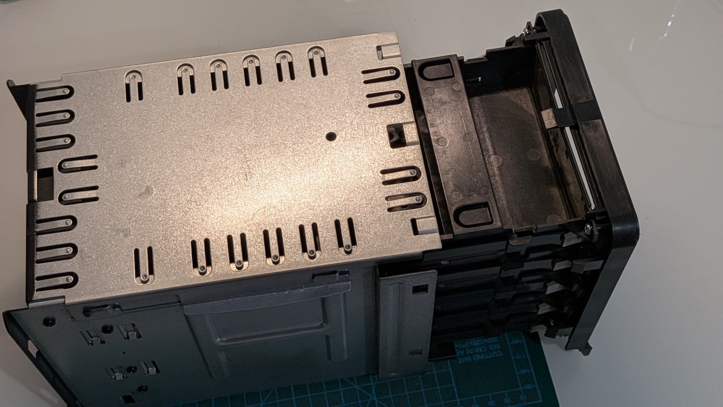
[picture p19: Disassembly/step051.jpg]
   
1. Remove the top and bottom screw on each side (4x PH1)  
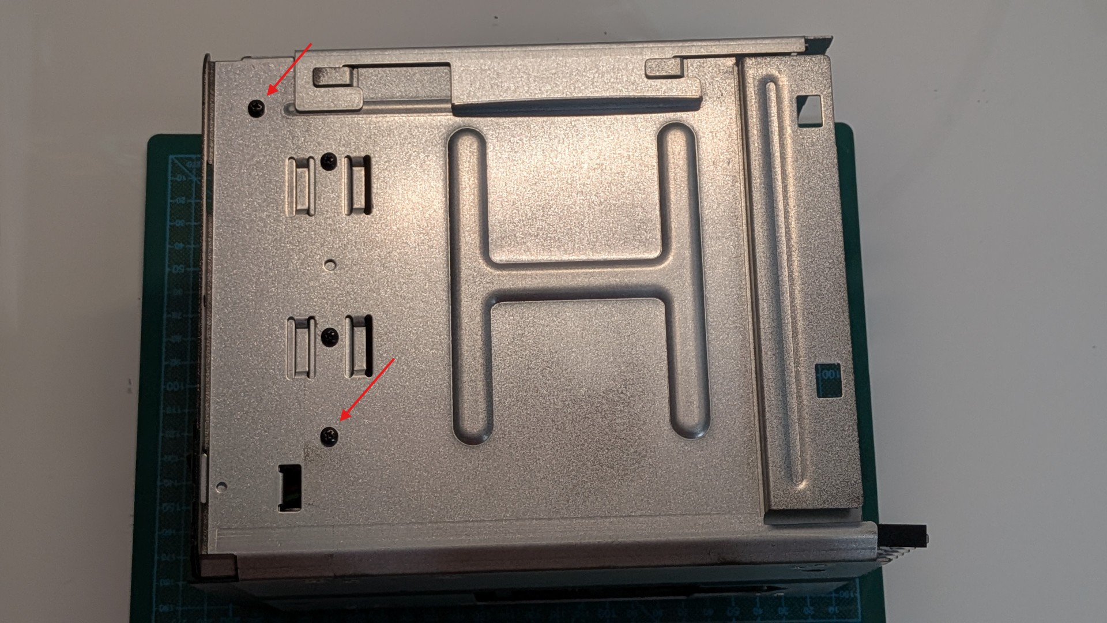
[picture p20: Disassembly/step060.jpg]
   
1. Slide the top of the case backwards (against the sides) for ~3-5mm and then turn the case around on its top  
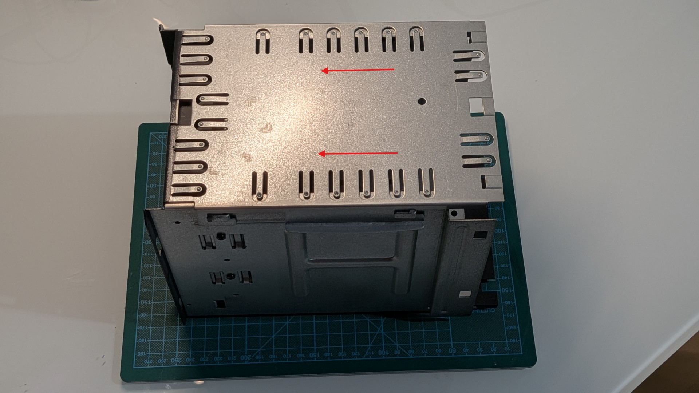
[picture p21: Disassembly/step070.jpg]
   
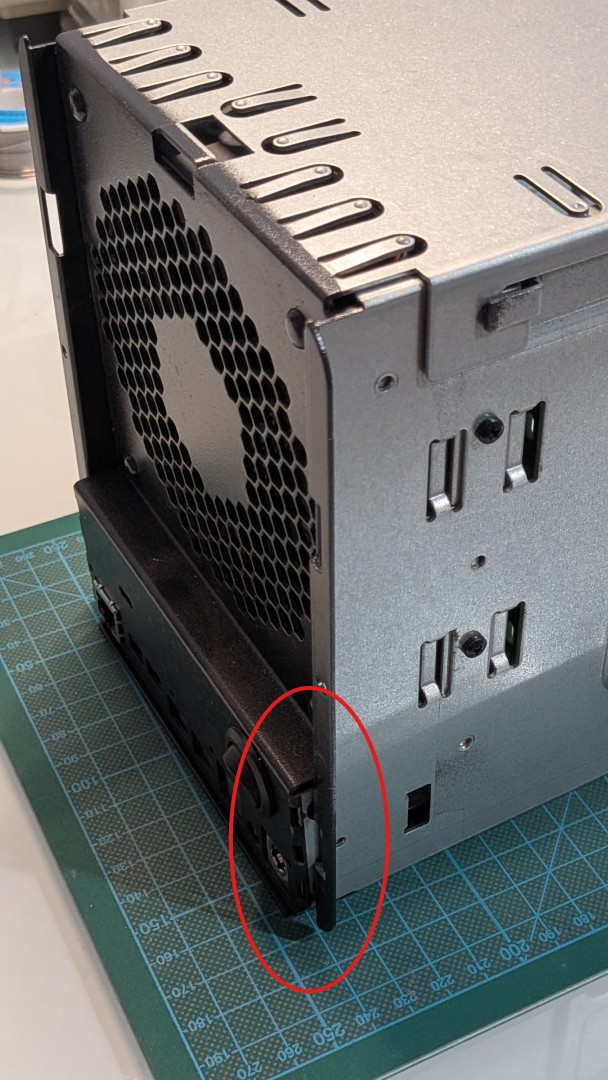
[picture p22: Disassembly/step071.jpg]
   
1. Try to pry the bottom part of the back (where the connector openings are) backwards. A flat hat screwdriver might help to lever against the chamfered edges  
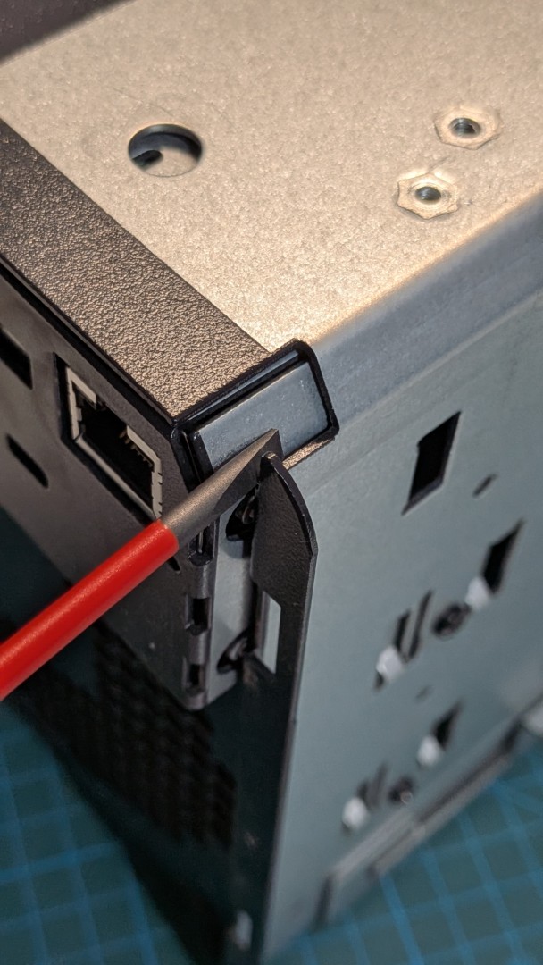
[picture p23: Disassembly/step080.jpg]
   
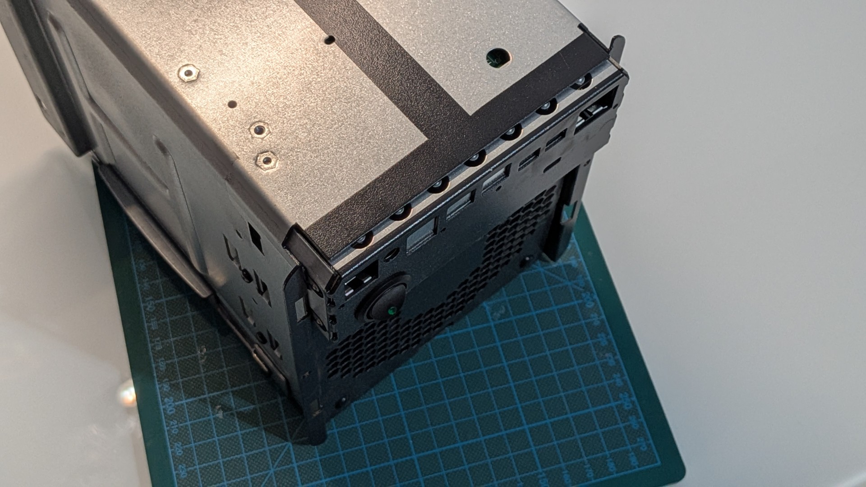
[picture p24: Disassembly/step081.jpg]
   
1. Turn it back right way up
1. Slide the top/back all the way back until the back side is free - then lift it carefully ~10mm. Be aware of the Power switch and Fan cables inside!  
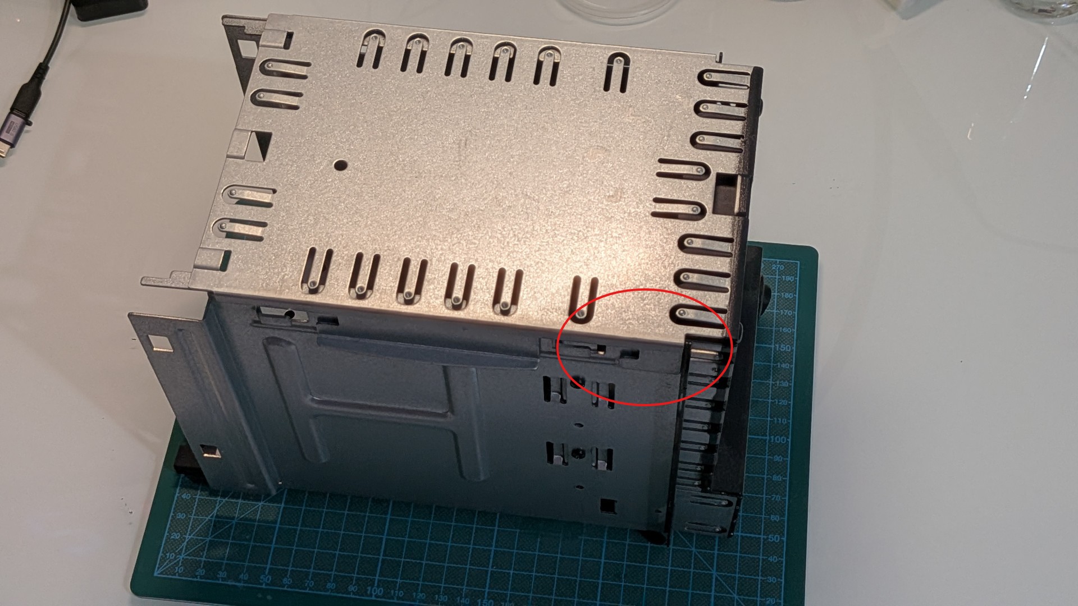
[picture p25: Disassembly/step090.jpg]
   
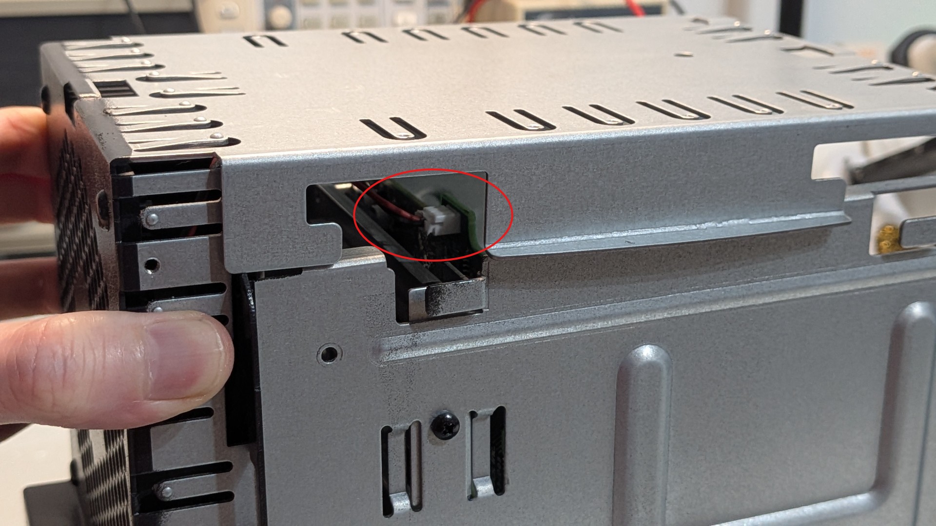
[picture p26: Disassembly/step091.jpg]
   
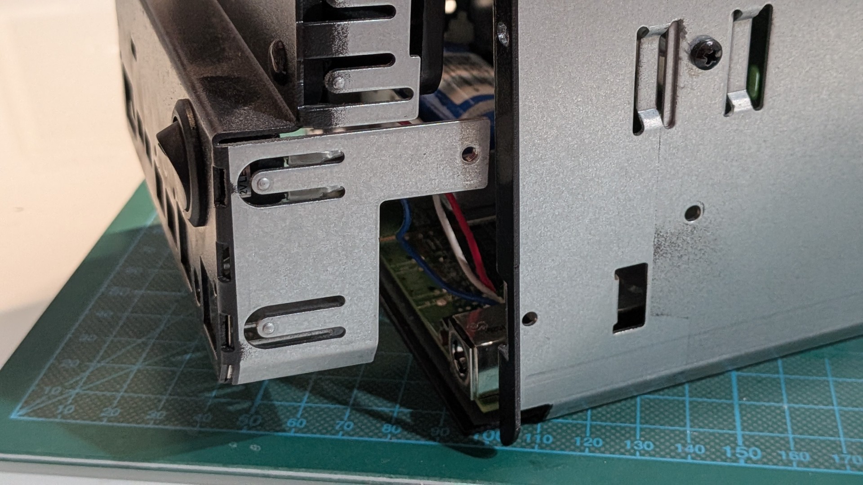
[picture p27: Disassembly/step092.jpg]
   
1. Carefully unplug the power switch from the right side, then unplug the Fan (can be done from the left side)  
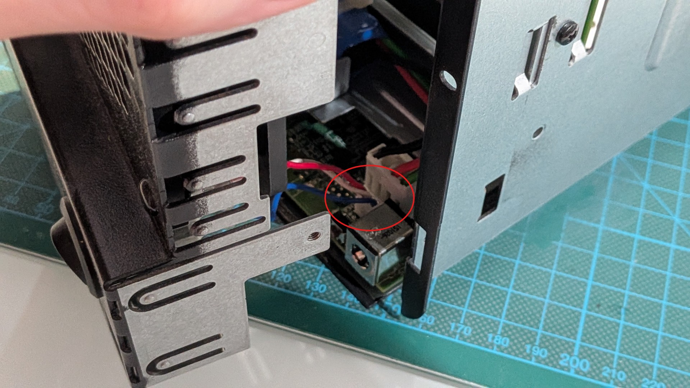
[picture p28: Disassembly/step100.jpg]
   
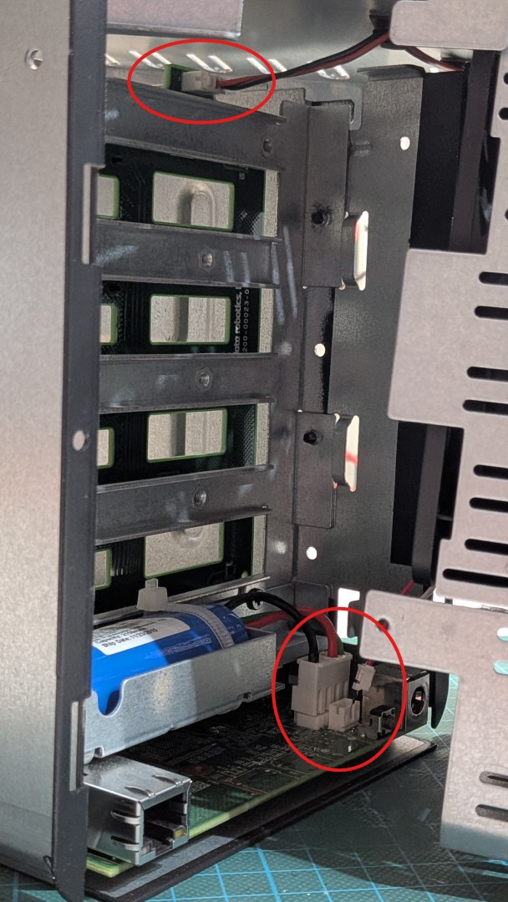
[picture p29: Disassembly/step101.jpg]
   
1. Remove the top/back
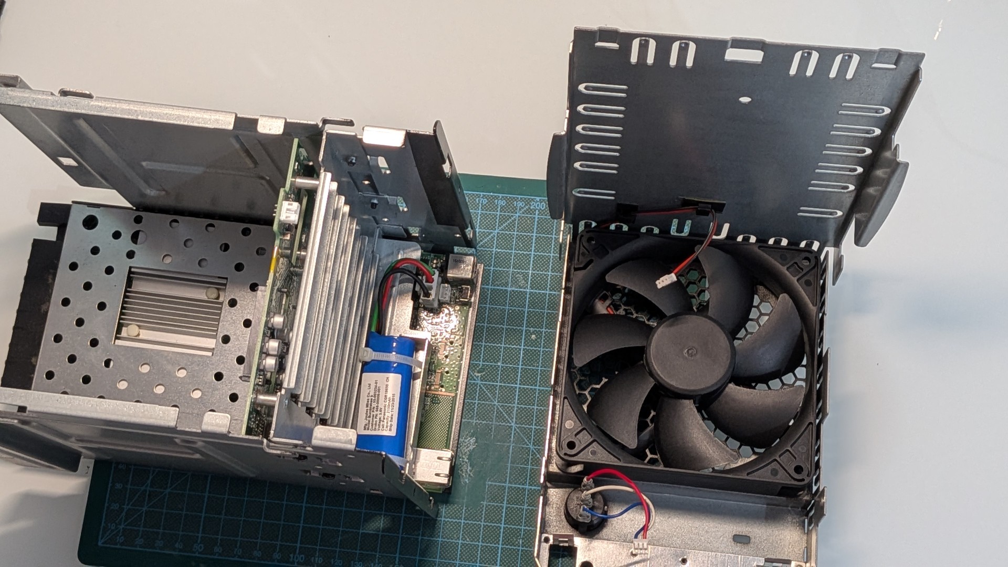
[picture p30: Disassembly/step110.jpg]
   
1. optionally: Use a flat hat screw driver or a dull pin to push out the plastic pegs, that hold the Fan, from the back side. Then unclip the Fan cable clips and remove the Fan  
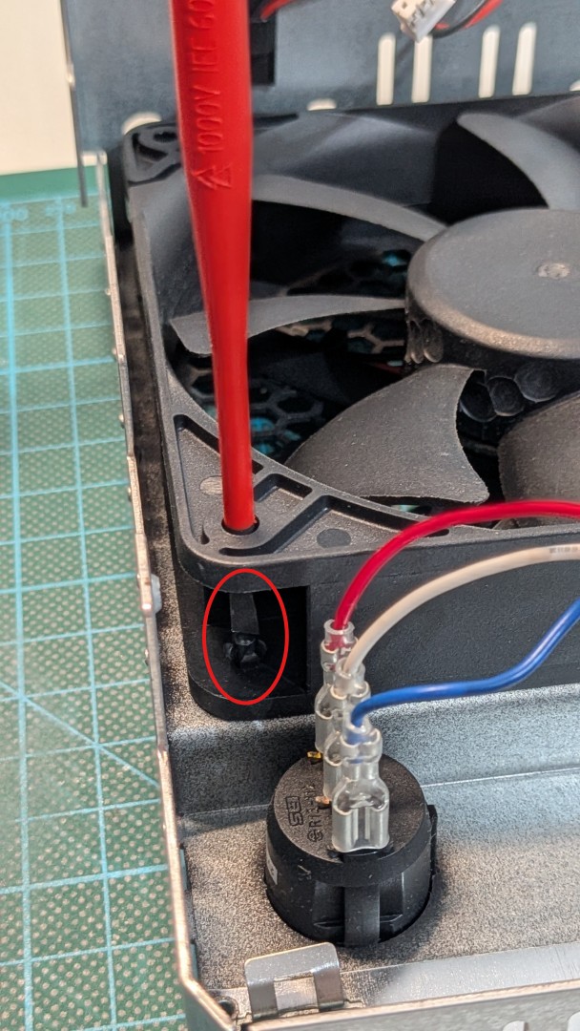
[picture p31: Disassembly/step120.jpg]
   
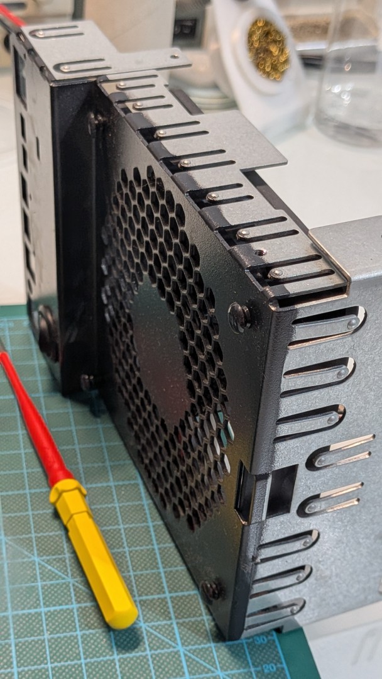
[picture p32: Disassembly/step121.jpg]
   
1. optionally: Remove the Power switch by pushing it from the back while carefully compressing the flaps on the side with a flat hat screwdriver  
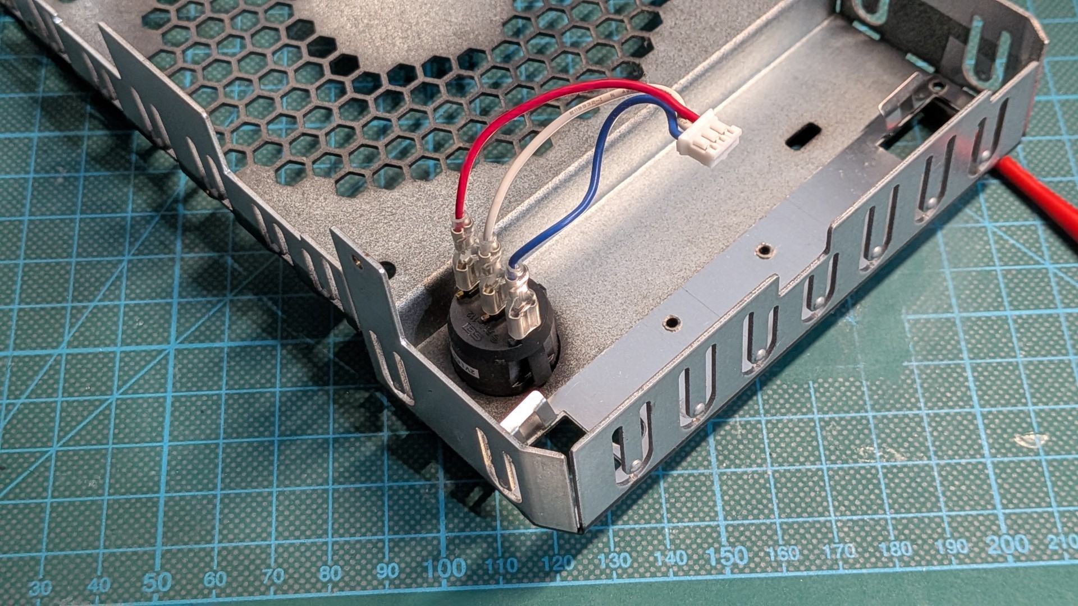
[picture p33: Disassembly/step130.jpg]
   
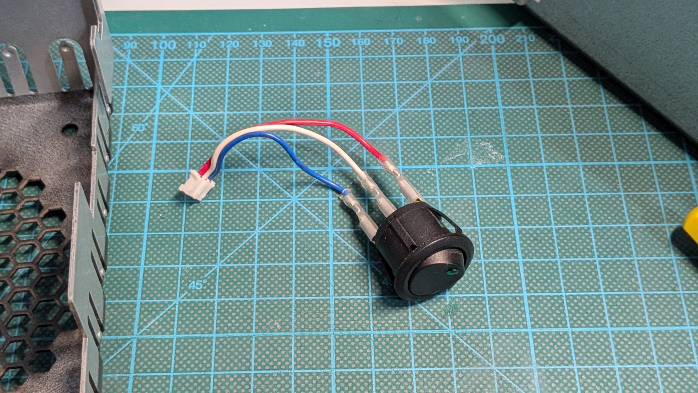
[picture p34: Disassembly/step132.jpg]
   
1. Unplug the battery  
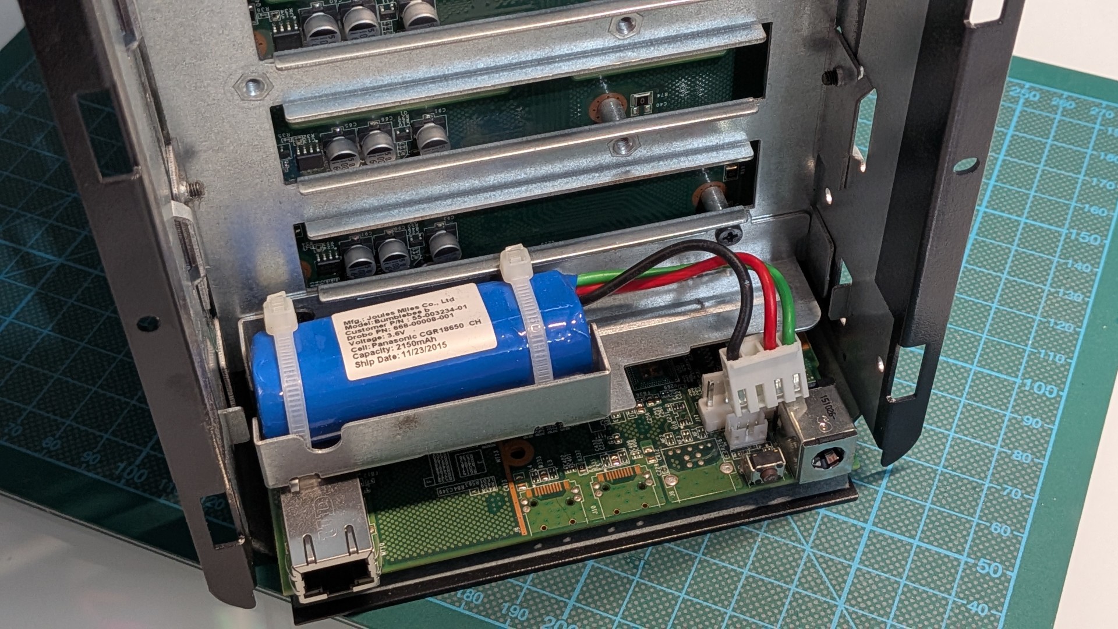
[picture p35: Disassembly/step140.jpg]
   
1. Remove the remaining two screws on each side (4x PH1)  
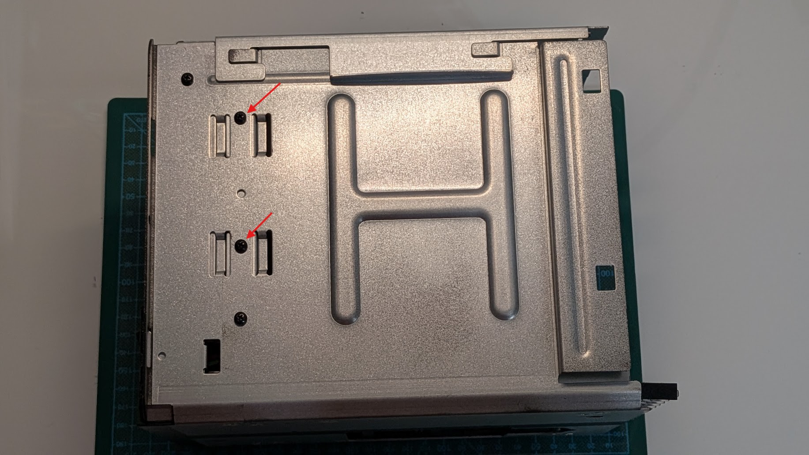
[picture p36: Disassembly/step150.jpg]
   
1. Carefully lift the backplane assembly up  
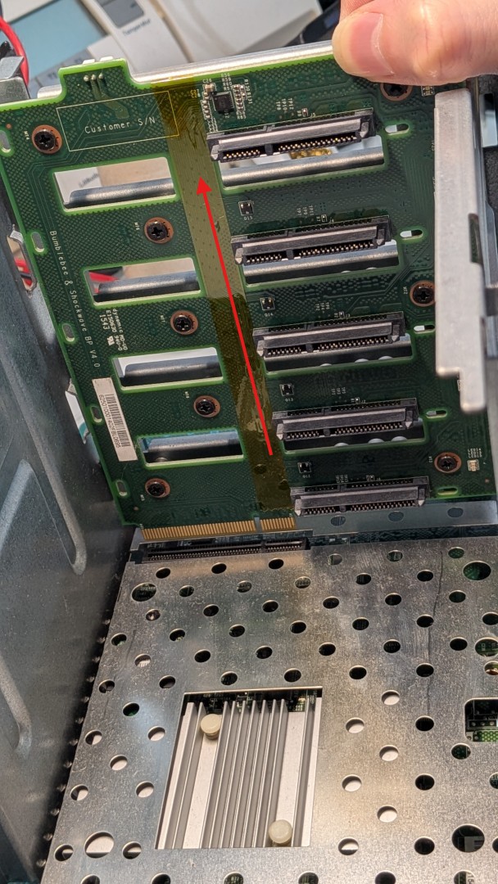
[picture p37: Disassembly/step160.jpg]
   
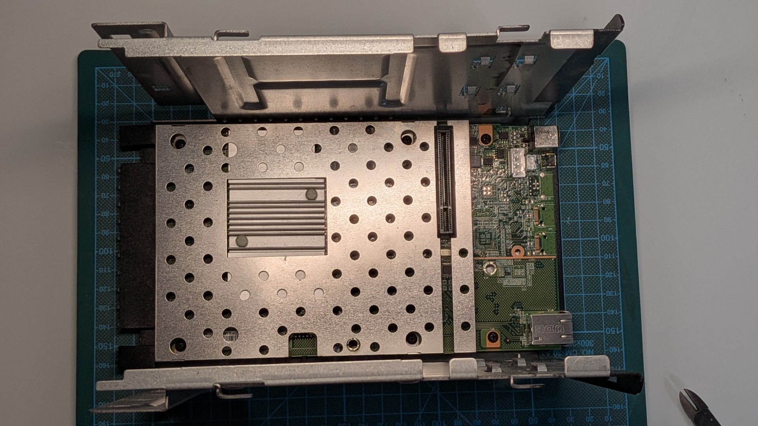
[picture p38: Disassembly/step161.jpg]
   
1. Unscrew the backplane from its frame (8x PH2)
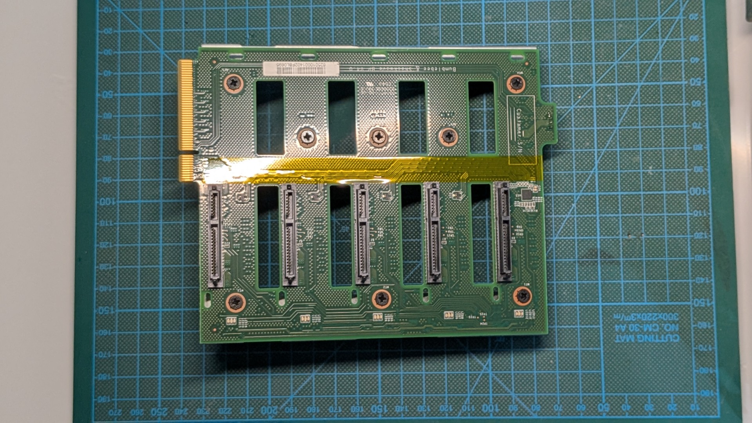
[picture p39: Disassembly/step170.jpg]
   
1. Unscrew battery holder from its frame (2x PH2)
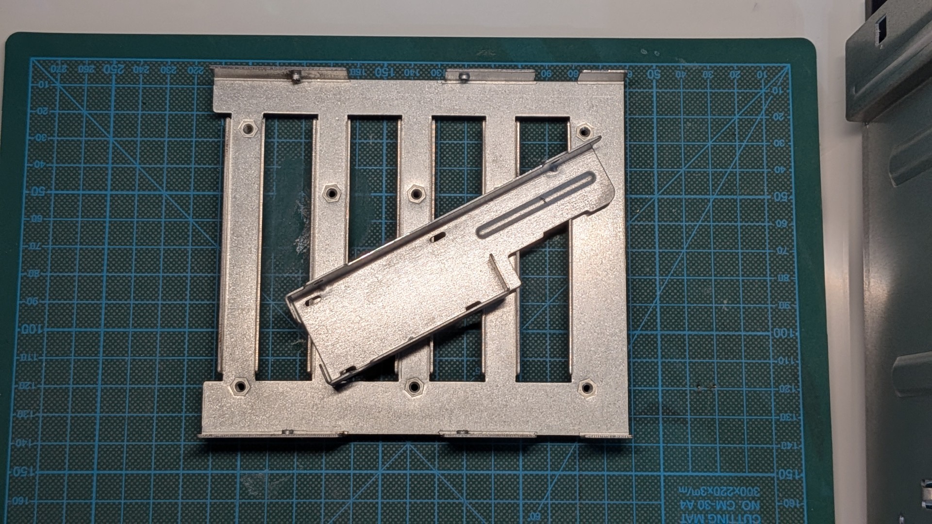
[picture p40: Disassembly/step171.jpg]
   
1. Unscrew the main PCB and its shield (6x PH1)  
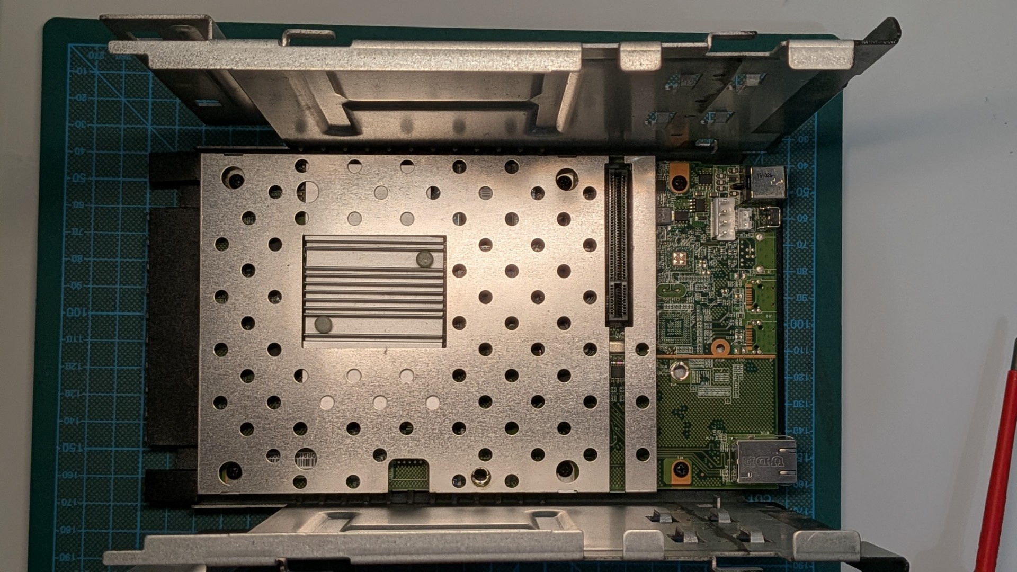
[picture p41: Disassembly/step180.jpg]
   
1. Carefully lift the PCB shield without bending its fingers on the side  
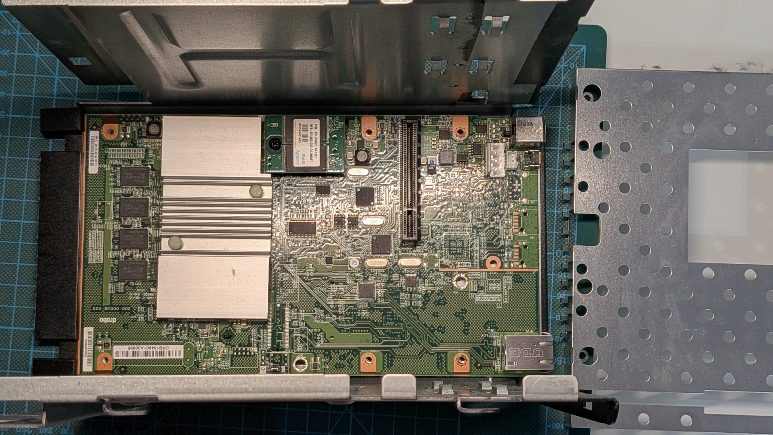
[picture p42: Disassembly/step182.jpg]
   
1. Remove the main PCB  
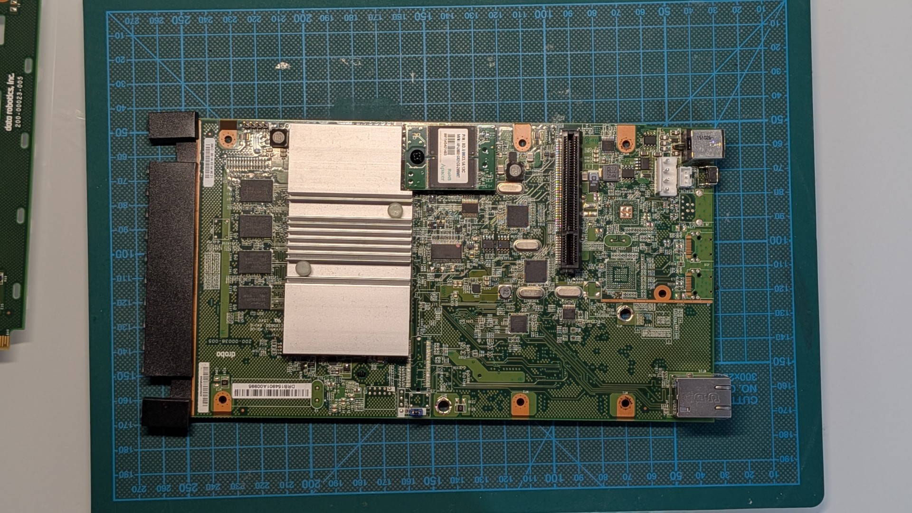
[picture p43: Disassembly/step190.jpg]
   
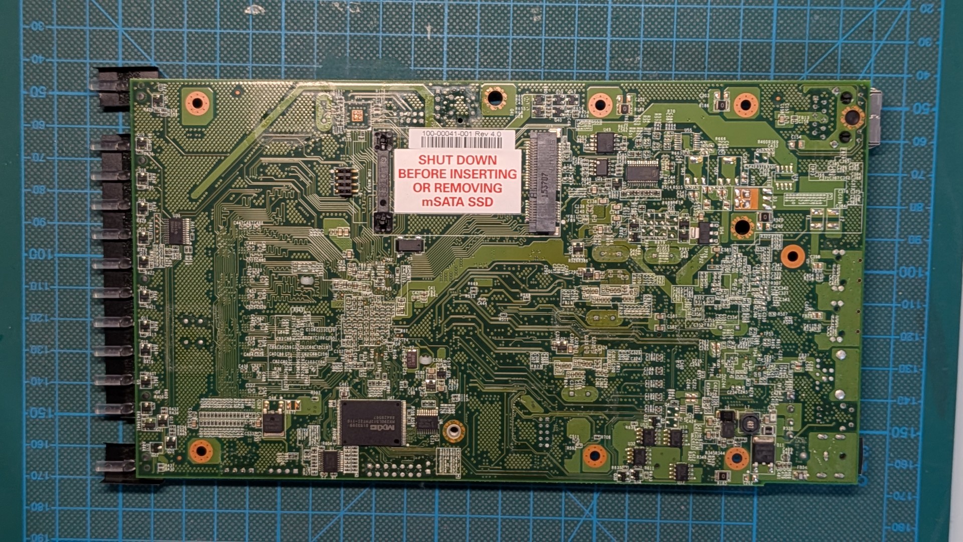
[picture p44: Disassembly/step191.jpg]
   
1. optionally: Unscrew the USB DOM (Disk on module) and lift it (1x PH1)  
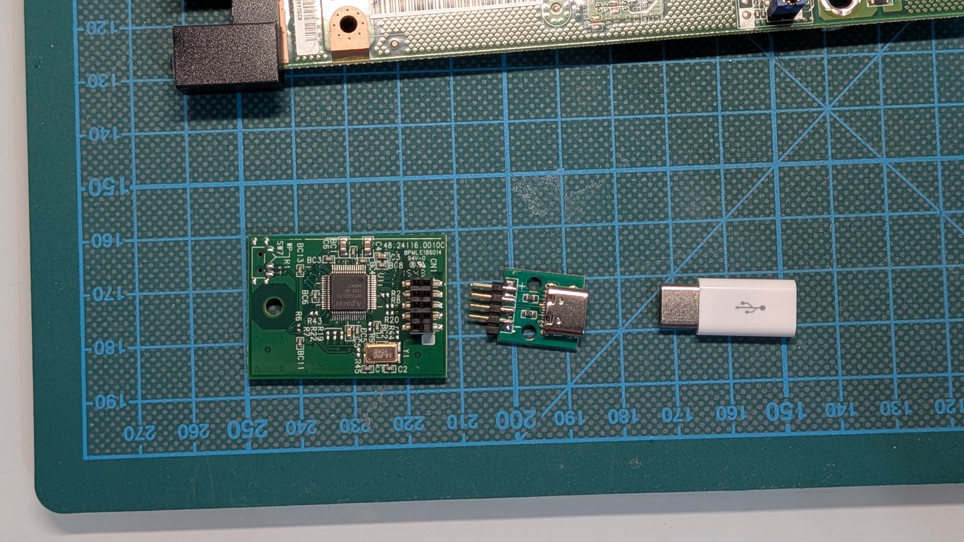
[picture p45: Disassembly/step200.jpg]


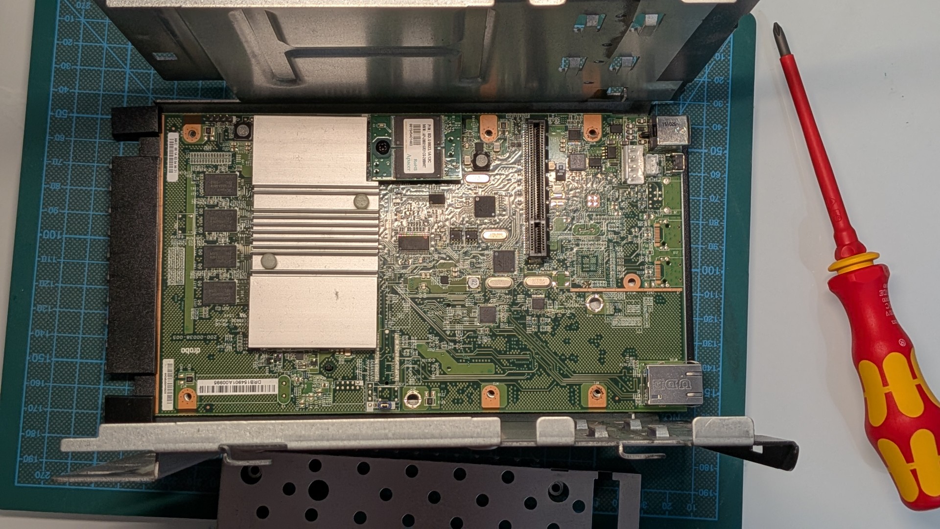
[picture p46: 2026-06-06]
Disassembly/step181.jpg

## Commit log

2026-06-05 add traces for working unit2
2026-06-20 alternative PCB carrier 3D print
    [Drobo-PCB-Carrier3.scad, Drobo-PCB-Carrier3.stl]
2026-06-20 more traces of unit1
2026-06-20 Unit2 traces and readme
